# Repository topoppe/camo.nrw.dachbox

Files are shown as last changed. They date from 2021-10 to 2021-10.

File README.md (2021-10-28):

Im Rahmen des EFRE-geförderten Projektes CAMO.NRW forschen Mitarbeiter der Hochschule Ruhr West zusammen mit Kollegen der Bergischen Universität Wuppertal und der Bergischen Struktur- & Wirtschaftsförderungsgesellschaft an der Zukunft der automatisierten Mobilität. An der Hochschule bestand schon eine Experimentalplattform bestehend aus verschiedenen Kameras, Radarsensoren, LiDAR und mehreren GNSS.
Jene Plattform war im Kofferraum eines PKWs verbaut, jedoch ohne die Beachtung gängiger Sicherheitsvorschriften und Normen. 
Durch die komplexe Einbauweise war die gesamte Plattform an einen einzelnen PKW gebunden. 
Im Rahmen dieser Arbeit wurde die vorhandene Sensortechnik auf einem austauschbaren Geräteträger montiert. Hierbei wurde sowohl auf Sicherheitsvorschriften als auch auf die einfache Montagemöglichkeit auf verschiedenen PKW geachtet. 
Der entstandene Geräteträger kann nun sowohl mobil als auch stationär, auf einem beliebigen PKW montiert oder in einer Laborumgebung ohne PKW genutzt werden.

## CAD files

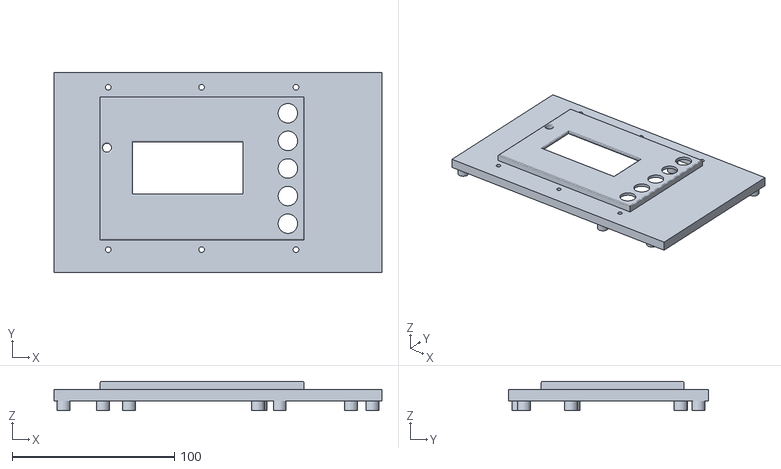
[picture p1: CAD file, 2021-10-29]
Mechanik/Gehäuse Steuergerät/aussenteil.stl
202.0 x 123.0 x 18.0

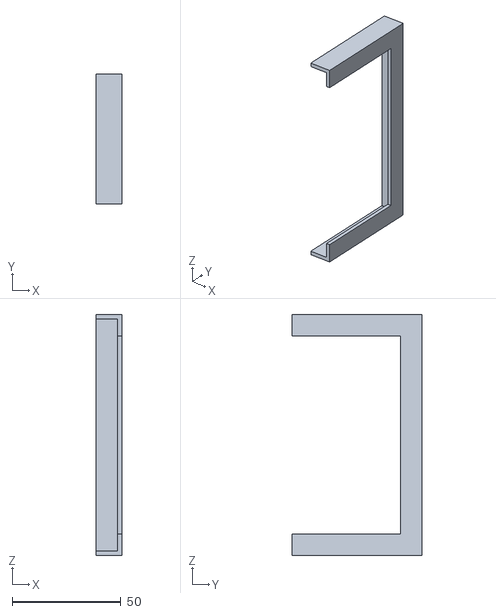
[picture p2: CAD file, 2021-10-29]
Mechanik/Halterung Cam-Sync-Box/Halterung Sync-Box v2.stl
12.0 x 60.0 x 111.0

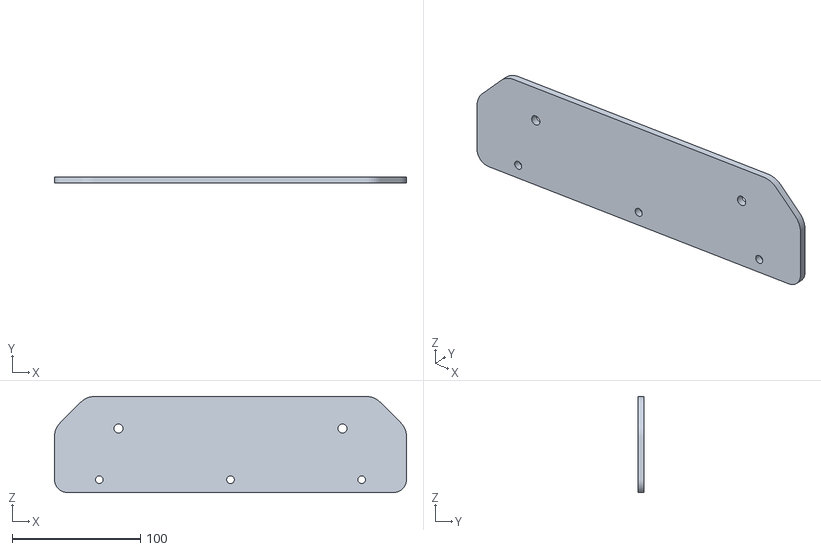
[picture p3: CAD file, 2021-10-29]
Mechanik/Halterung GPS/halterung gps v2.stl
275.0 x 5.00 x 75.0

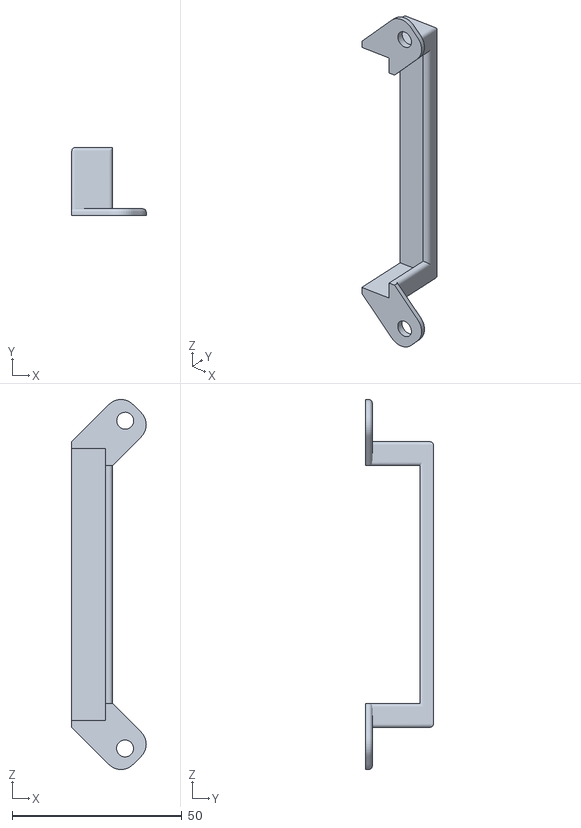
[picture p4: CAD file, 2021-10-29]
Mechanik/Halterung HDBaseT Sender/halterung_hdbaset_sender v1.stl
21.9 x 20.0 x 108.8

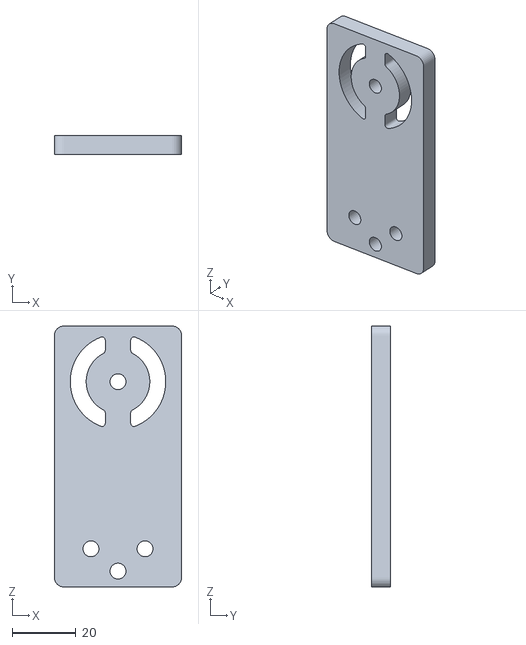
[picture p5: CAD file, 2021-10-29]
Mechanik/Halterung Kamera BlueFox/Halterung Kamera BlueFOX v2.stl
40.0 x 6.00 x 82.0

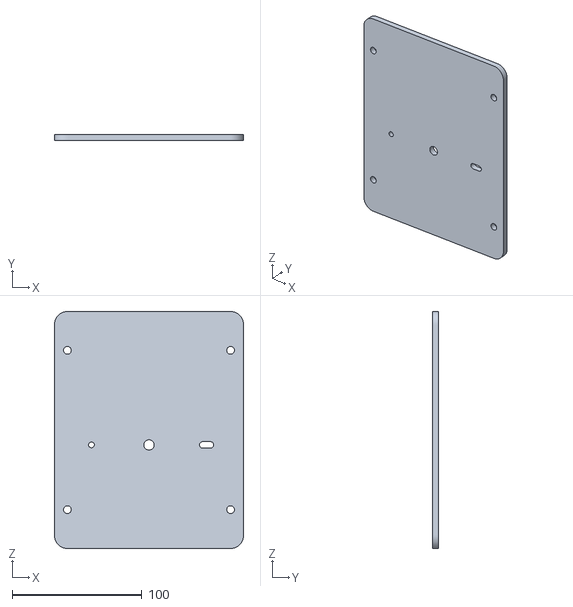
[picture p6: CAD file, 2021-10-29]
Mechanik/Halterung Lidar/halteplatte_lidart v2.stl
146.0 x 5.00 x 183.0

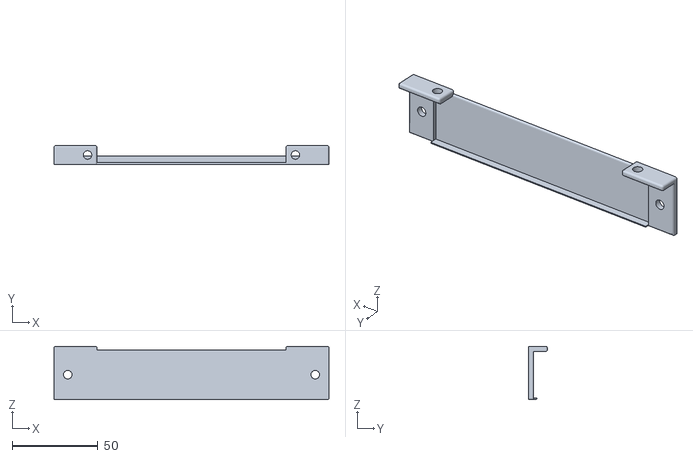
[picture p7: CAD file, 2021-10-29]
Mechanik/Halterung Netzteil 5V/halterung netzteil 5v v1.stl
160.0 x 11.0 x 31.0

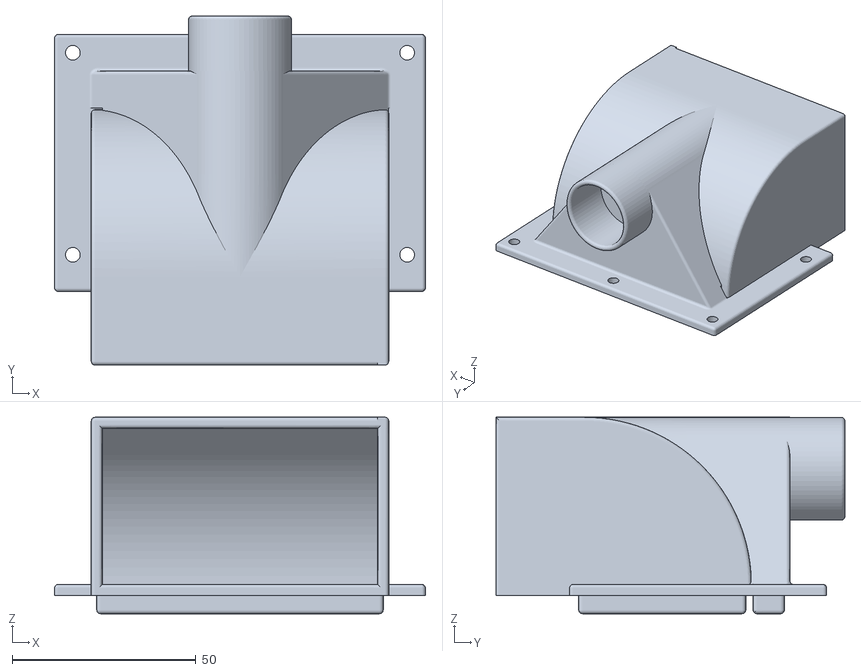
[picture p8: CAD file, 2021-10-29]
Mechanik/Kabelauslass/kabelauslass_innen v6.stl
101.0 x 95.0 x 53.5

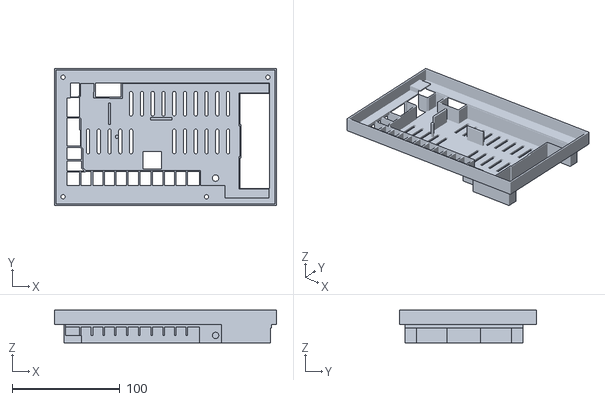
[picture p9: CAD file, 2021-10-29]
Mechanik/Gehäuse Steuergerät/deckel.stl
206.0 x 127.0 x 30.6

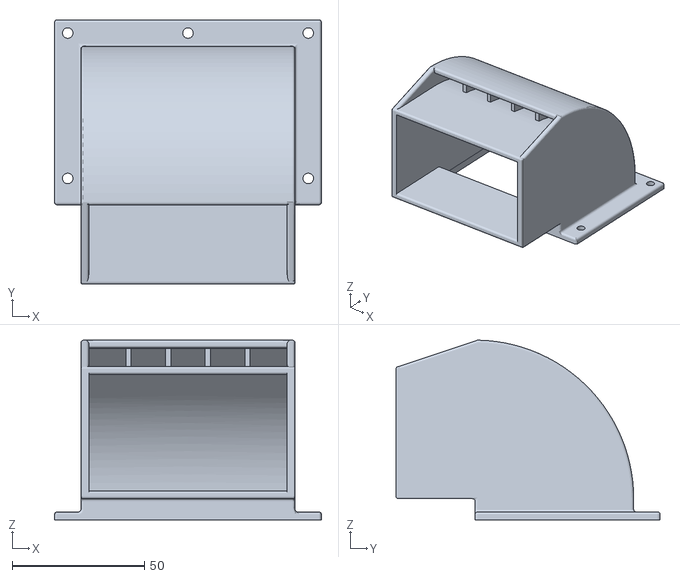
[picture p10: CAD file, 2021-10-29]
Mechanik/Kabelauslass/kabelauslass_aussen v8.stl
101.0 x 100.0 x 68.0

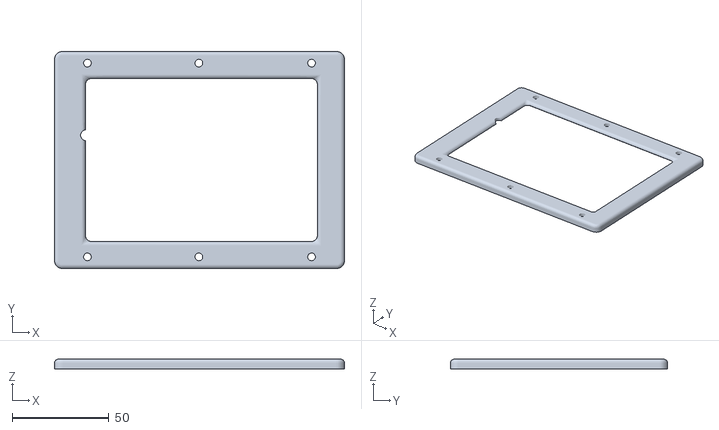
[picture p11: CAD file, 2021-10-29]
Mechanik/Gehäuse Steuergerät/rahmenabdeckung.stl
149.6 x 112.0 x 5.00

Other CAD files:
Mechanik/Halterung Cam-Sync-Box/Halterung Sync-Box v2.f3d
Mechanik/Halterung GPS/halterung gps v2.f3d
Mechanik/Halterung HDBaseT Sender/halterung_hdbaset_sender v1.f3d
Mechanik/Halterung Kamera BlueFox/Halterung Kamera BlueFOX v2.f3d
Mechanik/Halterung Lidar/halteplatte_lidart v2.f3d
Mechanik/Halterung Netzteil 5V/halterung netzteil 5v v1.f3d
Mechanik/Kabelauslass/kabelauslass_aussen v8.f3d
Mechanik/Kabelauslass/kabelauslass_innen v6.f3d

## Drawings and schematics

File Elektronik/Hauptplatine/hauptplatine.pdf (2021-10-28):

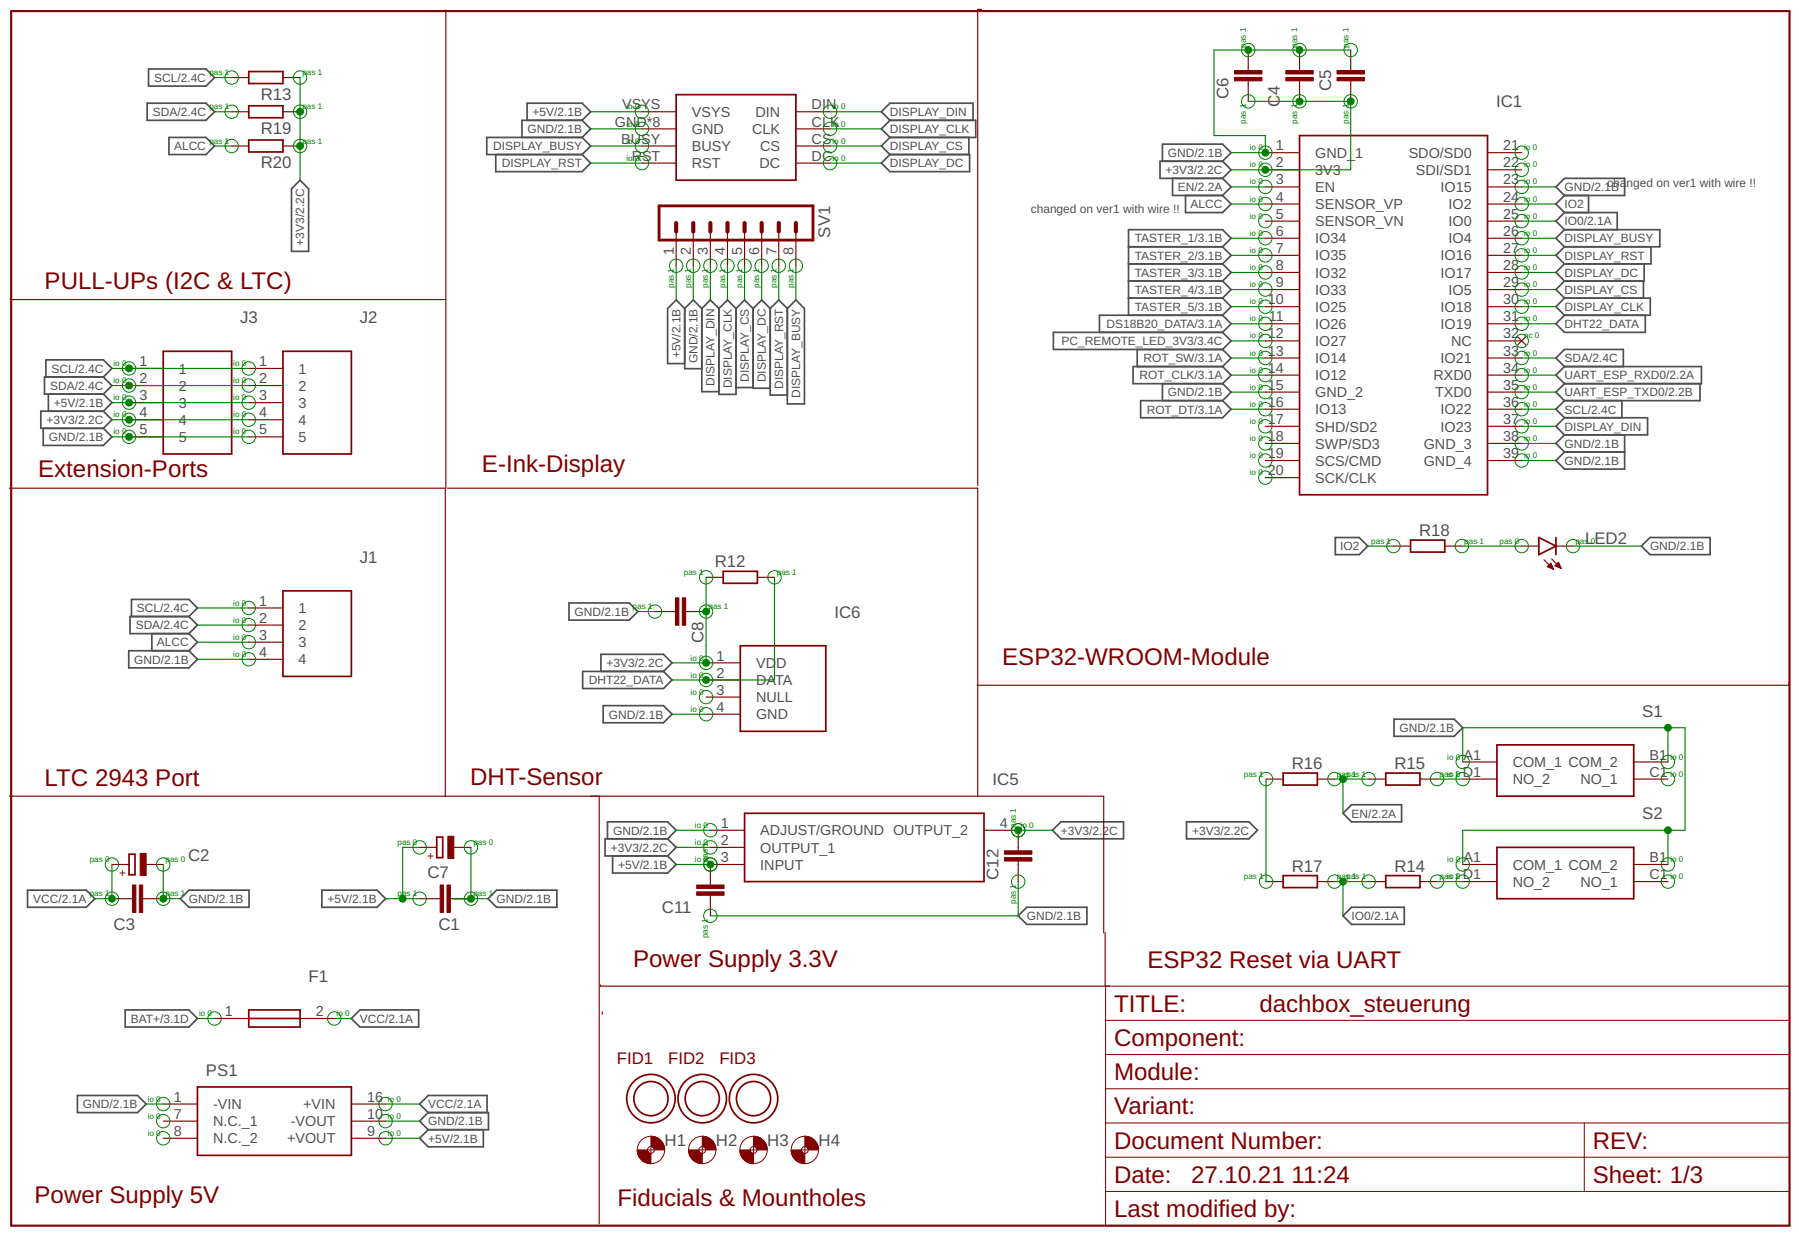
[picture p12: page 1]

2 | 2 io 0
3 | io 0 3
4 | 4 io 0

LTC 2943 Port | | J1 | DHT-Sensor

FID1 FID2 FID3 H1 H2 H3 H4 Fiducials & Mountholes | TITLE: dachbox_steuerung

Document Number: | REV:
Date: 27.10.21 11:24 | Sheet: 1/3

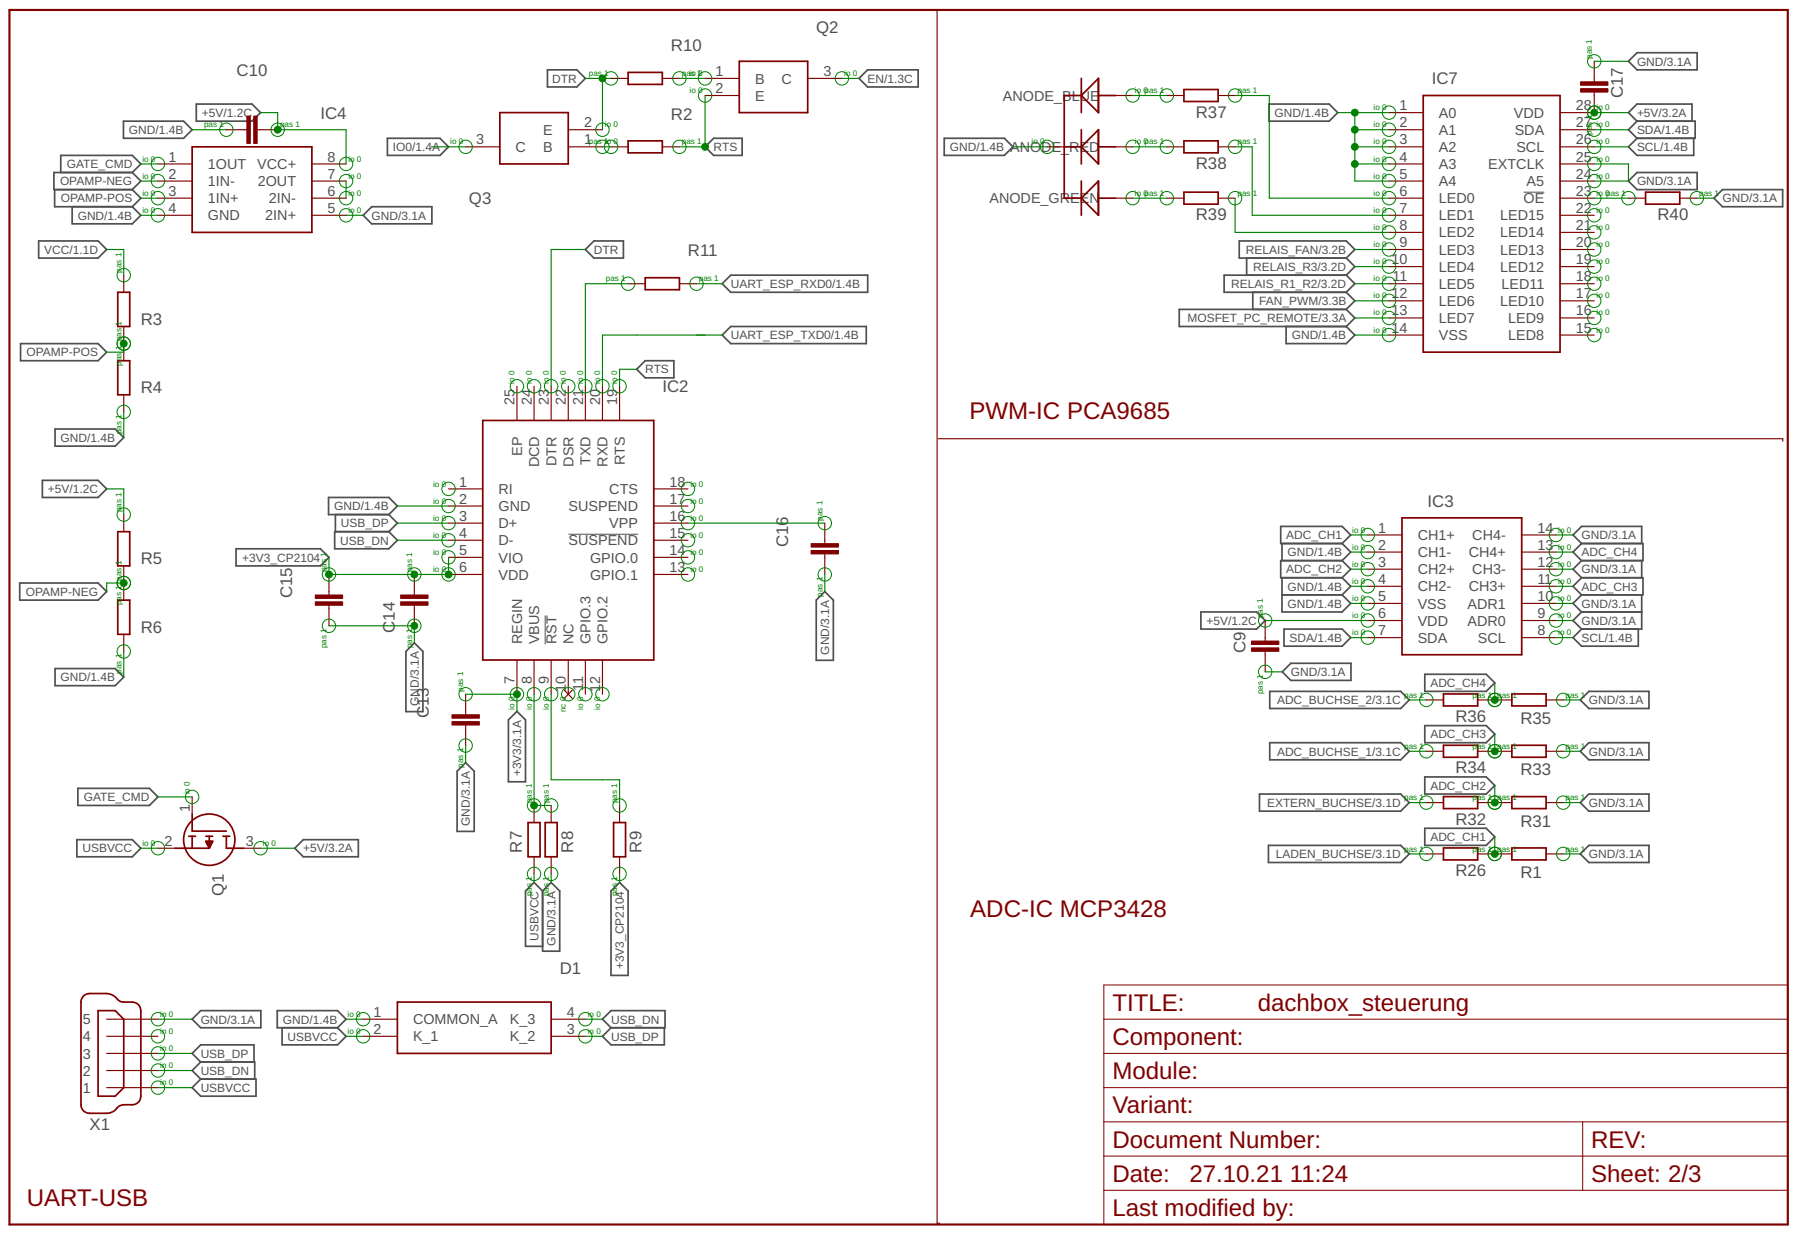
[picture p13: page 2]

pas 1 pas 1 pas 1 pas 1

Document Number: | REV:
Date: 27.10.21 11:24 | Sheet: 2/3

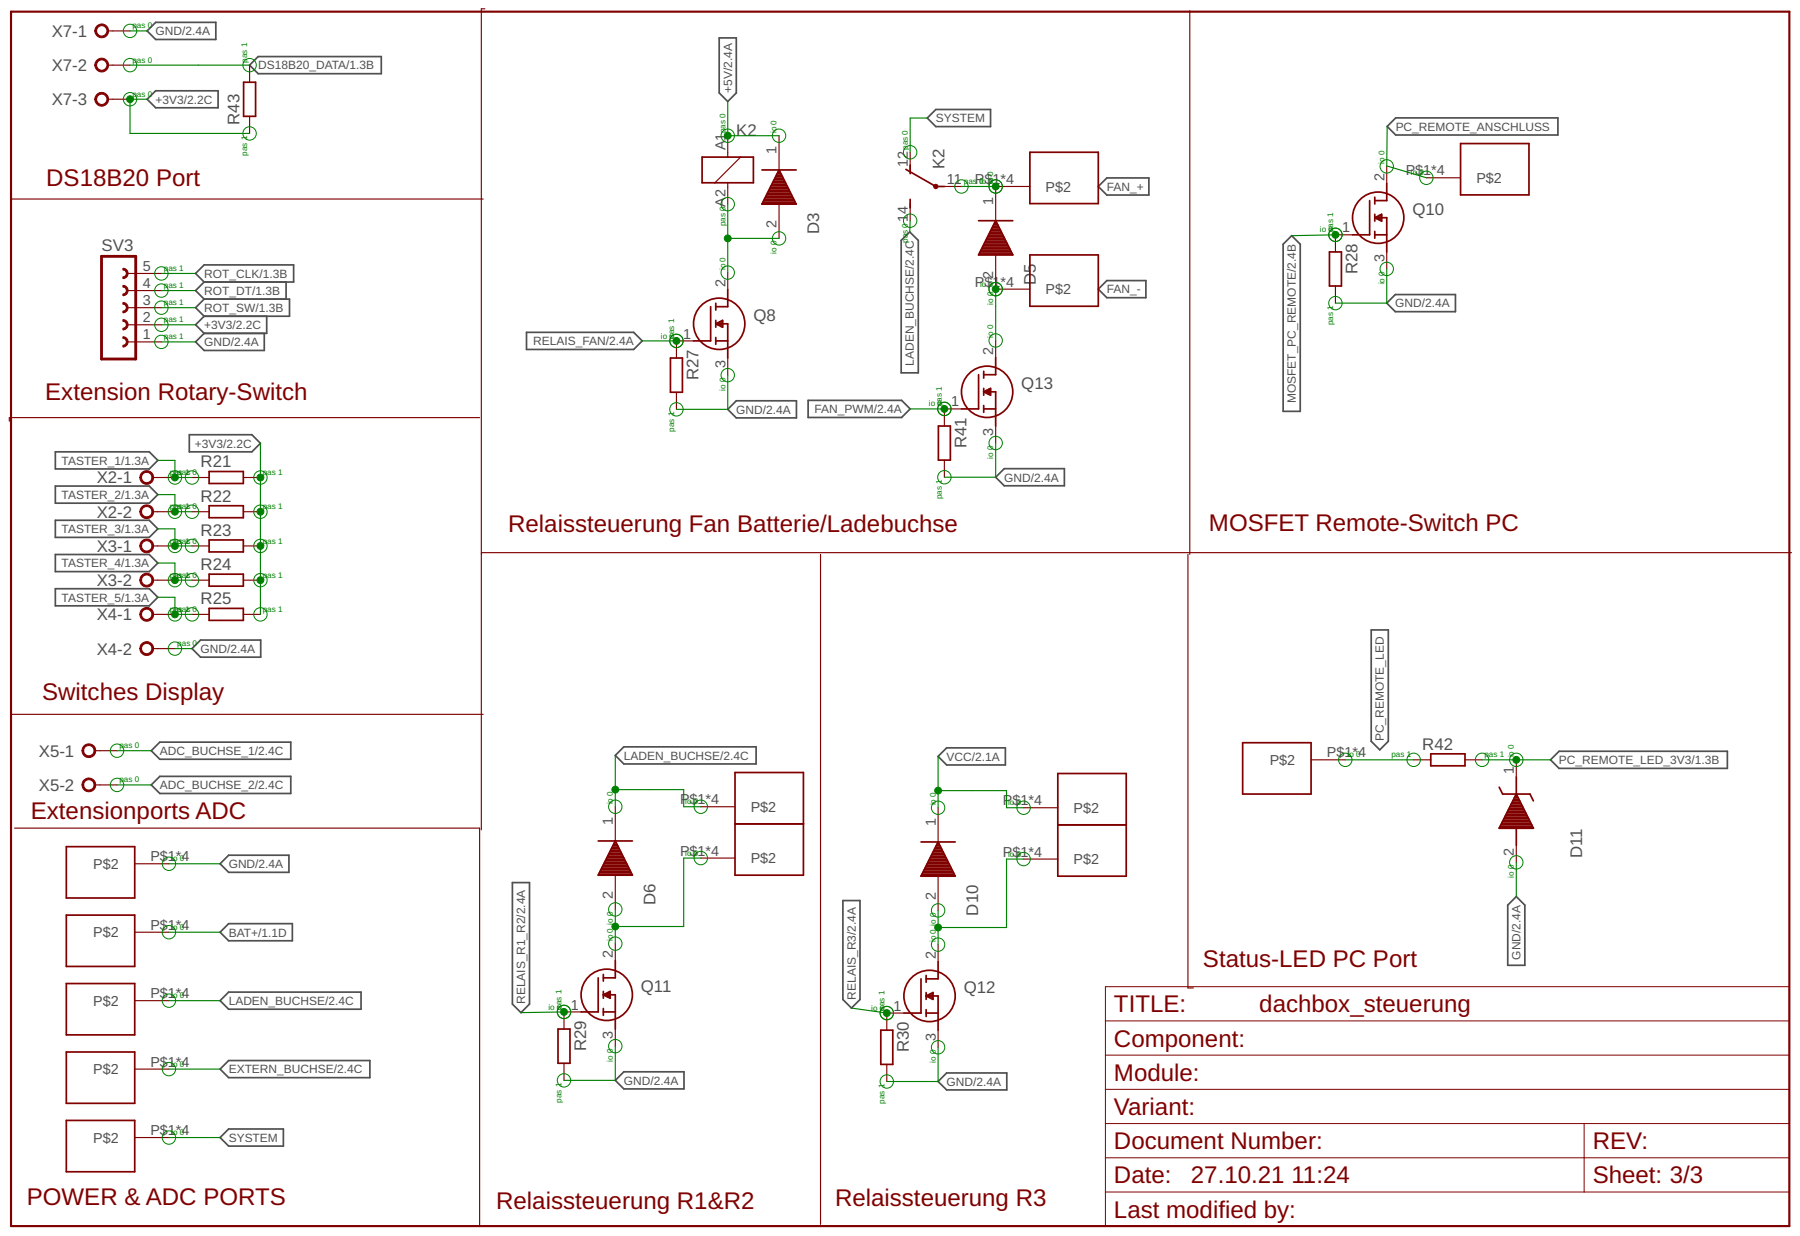
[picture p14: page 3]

io 0 io 0 pas 0 pas 0

Status-LED PC Port
dachbox_steuerung

Document Number: | REV:
Date: 27.10.21 11:24 | Sheet: 3/3

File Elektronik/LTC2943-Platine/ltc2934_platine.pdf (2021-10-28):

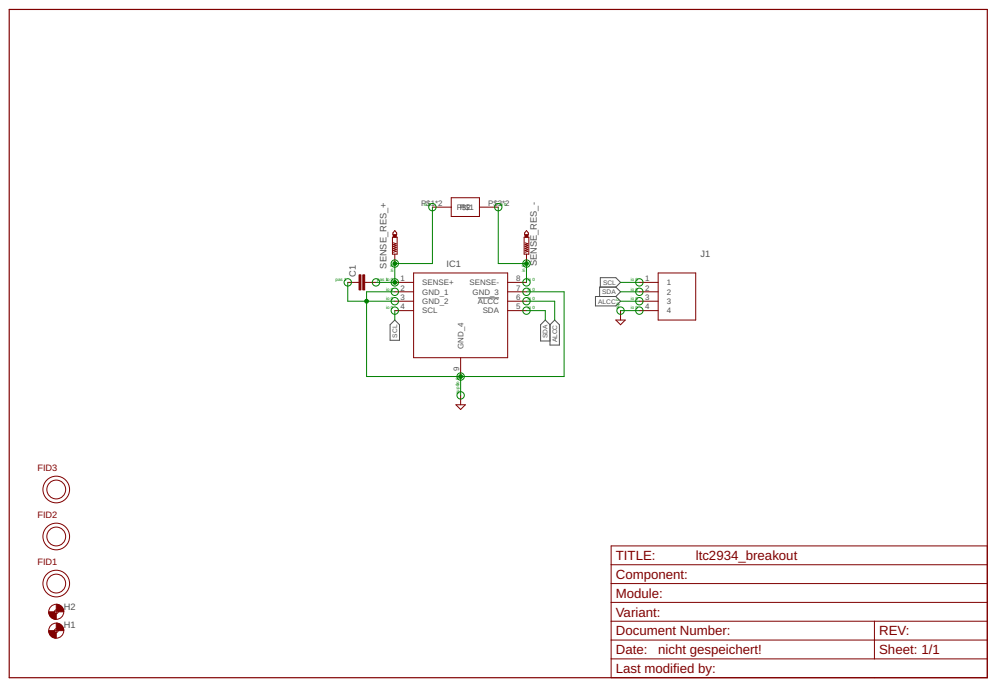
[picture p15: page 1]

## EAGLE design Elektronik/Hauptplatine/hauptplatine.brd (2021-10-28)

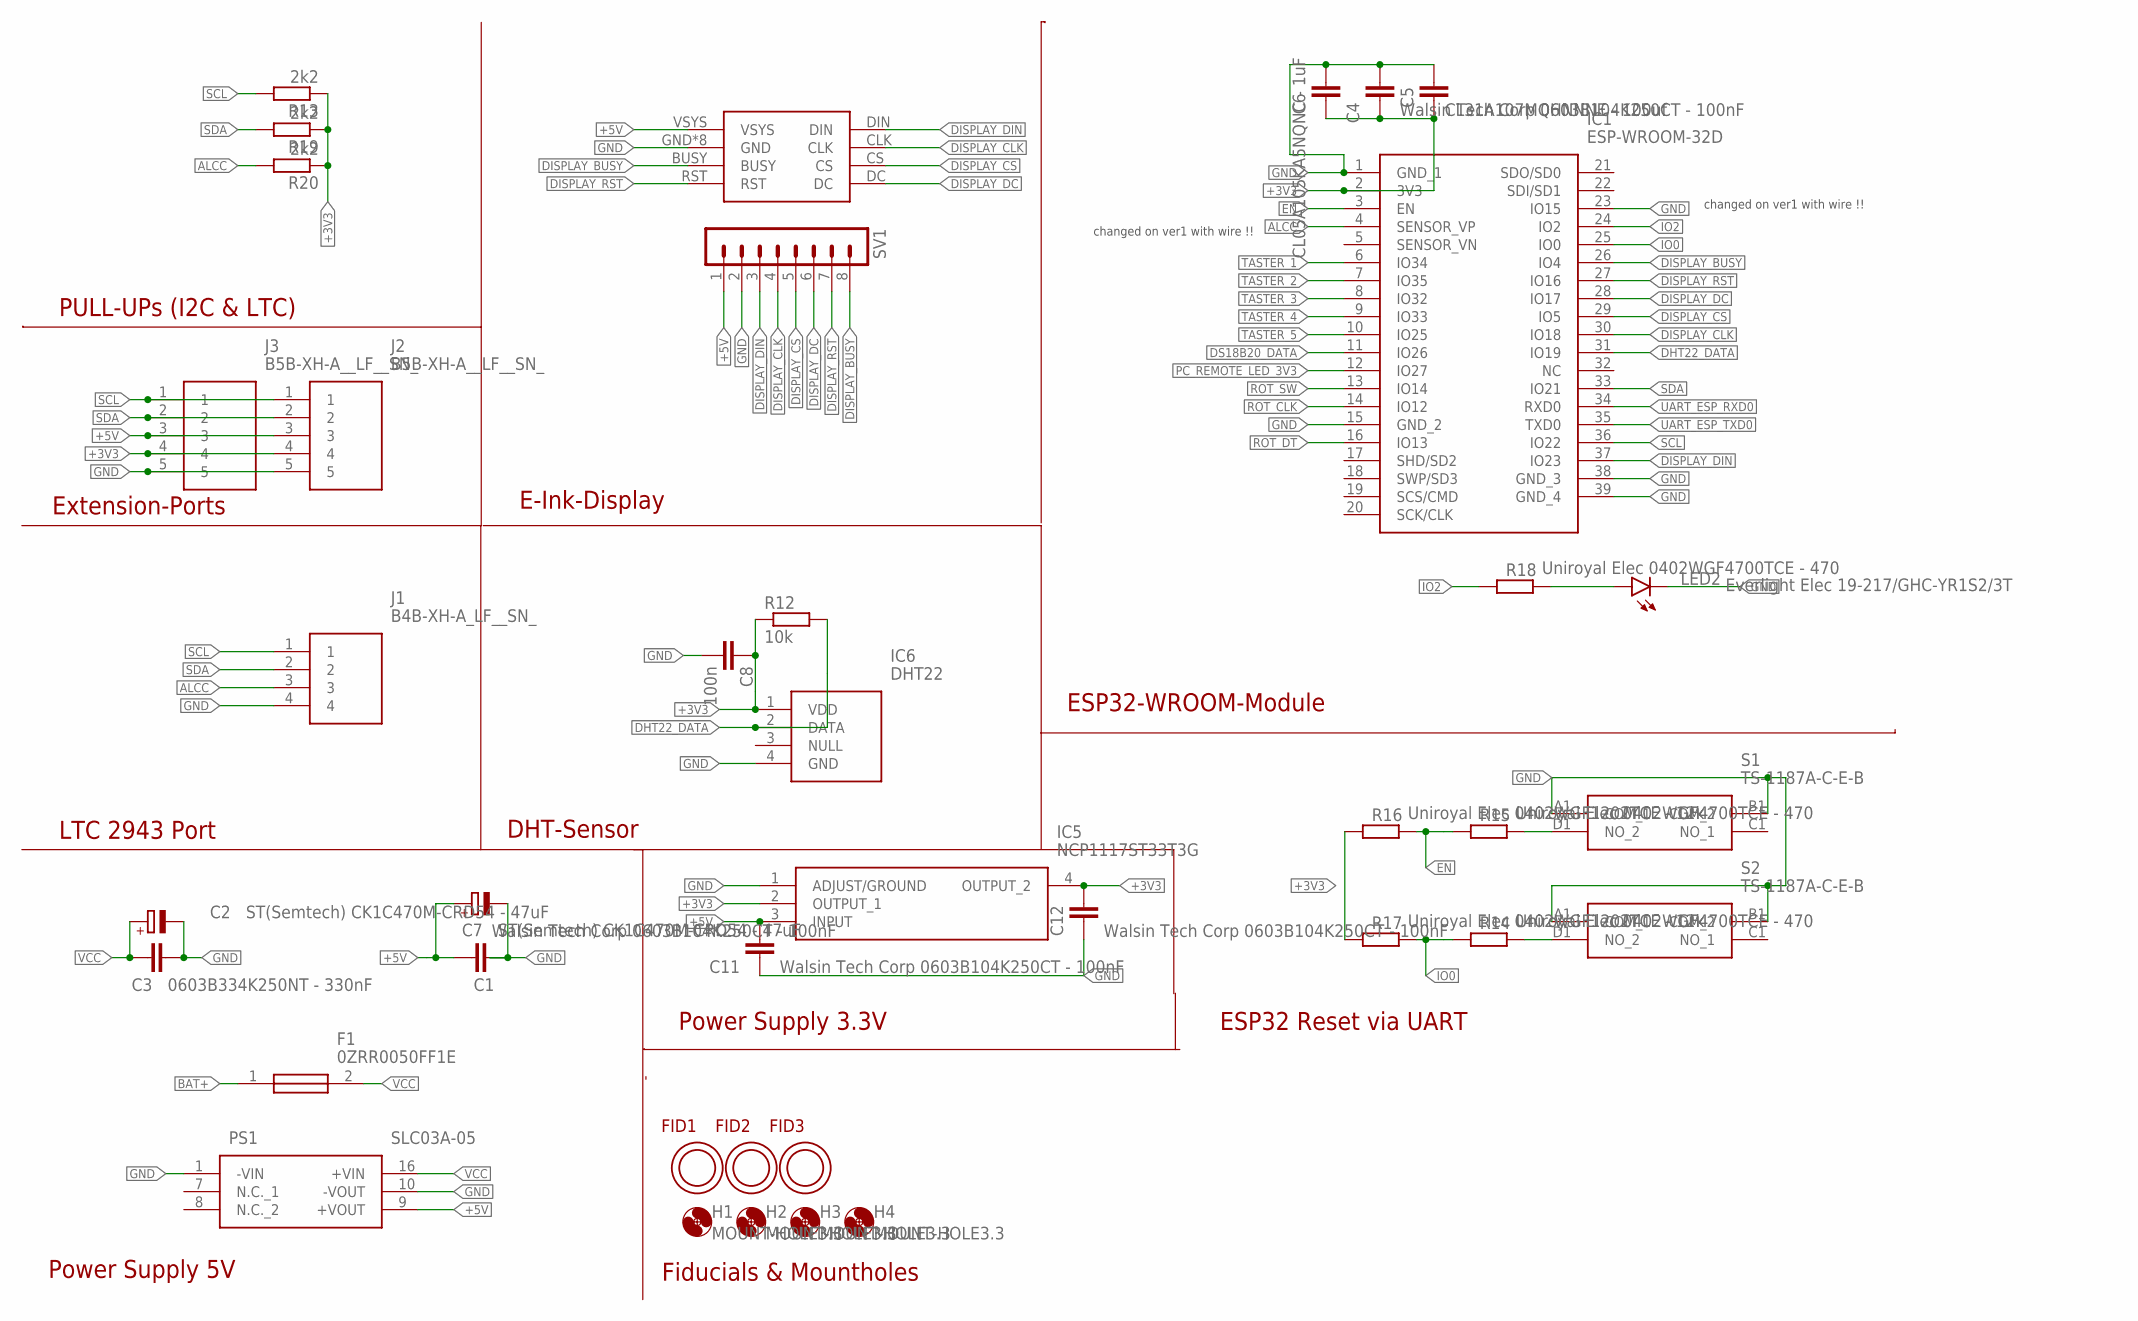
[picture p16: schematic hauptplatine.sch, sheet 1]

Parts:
C1, C4, C11, C12: Walsin Tech Corp 0603B104K250CT - 100nF; C0603
C2, C7: ST(Semtech) CK1C470M-CRD54 - 47uF; PANASONIC_C
C3: 0603B334K250NT - 330nF; C0603
C5: CL31A107MQHNNNE - 100uf; C1206
C6: CL05A105KA5NQNC - 1uF; C0402
C8: 100n; C1206
F1: 0ZRR0050FF1E
FID1, FID2, FID3: OPEN-PNP-FIDUCIAL
H1, H2, H3, H4: MOUNT-HOLE3.3; 3,3
IC1: ESP-WROOM-32D; ESPWROOM32D
IC5: NCP1117ST33T3G; SOT230P700X180-4N
IC6: DHT22
J1: B4B-XH-A_LF__SN_; B4BXHALFSN
J2, J3: B5B-XH-A__LF__SN_; SHDR5W64P0X250_1X5_1490X575X70
LED2: Everlight Elec 19-217/GHC-YR1S2/3T; CHIPLED_0603
PS1: SLC03A-05; SLC03A05
R12: 10k; R1206
R13, R19, R20: 2k2; R1206
R14, R15, R18: Uniroyal Elec 0402WGF4700TCE - 470; R0402
R16, R17: Uniroyal Elec 0402WGF1202TCE - 12k; R0402
S1, S2: TS-1187A-C-E-B; TS1187ACEB
SV1: MA08-1
U$1: PICO-EPAPER-2.9-V3

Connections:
+3V3: C4.1, C5.2, C6.1, C8.1, C12.2, IC1.2 (3V3), IC5.2 (OUTPUT_1), IC5.4 (OUTPUT_2), IC6.1 (VDD), J2.4, J3.4, R12.1, R13.1, R16.1, R17.1, R19.1, R20.1; also elsewhere on the board
+5V: C1.1, C7.+, C11.2, IC5.3 (INPUT), J2.3, J3.3, PS1.9 (+VOUT), SV1.1, U$1.VSYS; also elsewhere on the board
ALCC: IC1.4 (SENSOR_VP), J1.3, R20.2
BAT+: F1.1; also elsewhere on the board
DHT22_DATA: IC1.31 (IO19), IC6.2 (DATA), R12.2
DISPLAY_BUSY: IC1.26 (IO4), SV1.8, U$1.BUSY
DISPLAY_CLK: IC1.30 (IO18), SV1.4, U$1.CLK
DISPLAY_CS: IC1.29 (IO5), SV1.5, U$1.CS
DISPLAY_DC: IC1.28 (IO17), SV1.6, U$1.DC
DISPLAY_DIN: IC1.37 (IO23), SV1.3, U$1.DIN
DISPLAY_RST: IC1.27 (IO16), SV1.7, U$1.RST
DS18B20_DATA: IC1.11 (IO26); also elsewhere on the board
EN: IC1.3 (EN), R15.1, R16.2; also elsewhere on the board
GND: C1.2, C2.-, C3.1, C4.2, C5.1, C6.2, C7.-, C8.2, C11.1, C12.1, IC1.1 (GND_1), IC1.15 (GND_2), IC1.23 (IO15), IC1.38 (GND_3), IC1.39 (GND_4), IC5.1 (ADJUST/GROUND), IC6.4 (GND), J1.4, J2.5, J3.5, LED2.C, PS1.1 (-VIN), PS1.10 (-VOUT), S1.A1 (COM_1), S1.B1 (COM_2), S2.A1 (COM_1), S2.B1 (COM_2), SV1.2, U$1.GND, U$1.GND1 (GND), U$1.GND2 (GND), U$1.GND3 (GND), U$1.GND4 (GND), U$1.GND5 (GND), U$1.GND6 (GND), U$1.GND7 (GND); also elsewhere on the board
IO0: IC1.25 (IO0), R14.1, R17.2; also elsewhere on the board
IO2: IC1.24 (IO2), R18.1
unnamed: R15.2, S1.D1 (NO_2)
unnamed: R14.2, S2.D1 (NO_2)
unnamed: LED2.A, R18.2
PC_REMOTE_LED_3V3: IC1.12 (IO27); also elsewhere on the board
ROT_CLK: IC1.14 (IO12); also elsewhere on the board
ROT_DT: IC1.16 (IO13); also elsewhere on the board
ROT_SW: IC1.13 (IO14); also elsewhere on the board
SCL: IC1.36 (IO22), J1.1, J2.1, J3.1, R13.2; also elsewhere on the board
SDA: IC1.33 (IO21), J1.2, J2.2, J3.2, R19.2; also elsewhere on the board
TASTER_1: IC1.6 (IO34); also elsewhere on the board
TASTER_2: IC1.7 (IO35); also elsewhere on the board
TASTER_3: IC1.8 (IO32); also elsewhere on the board
TASTER_4: IC1.9 (IO33); also elsewhere on the board
TASTER_5: IC1.10 (IO25); also elsewhere on the board
UART_ESP_RXD0: IC1.34 (RXD0); also elsewhere on the board
UART_ESP_TXD0: IC1.35 (TXD0); also elsewhere on the board
VCC: C2.+, C3.2, F1.2, PS1.16 (+VIN); also elsewhere on the board

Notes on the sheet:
Power Supply 5V
changed on ver1 with wire !!
DHT-Sensor
Extension-Ports
PULL-UPs (I2C & LTC)
E-Ink-Display
LTC 2943 Port
ESP32-WROOM-Module
ESP32 Reset via UART
Power Supply 3.3V
Fiducials & Mountholes

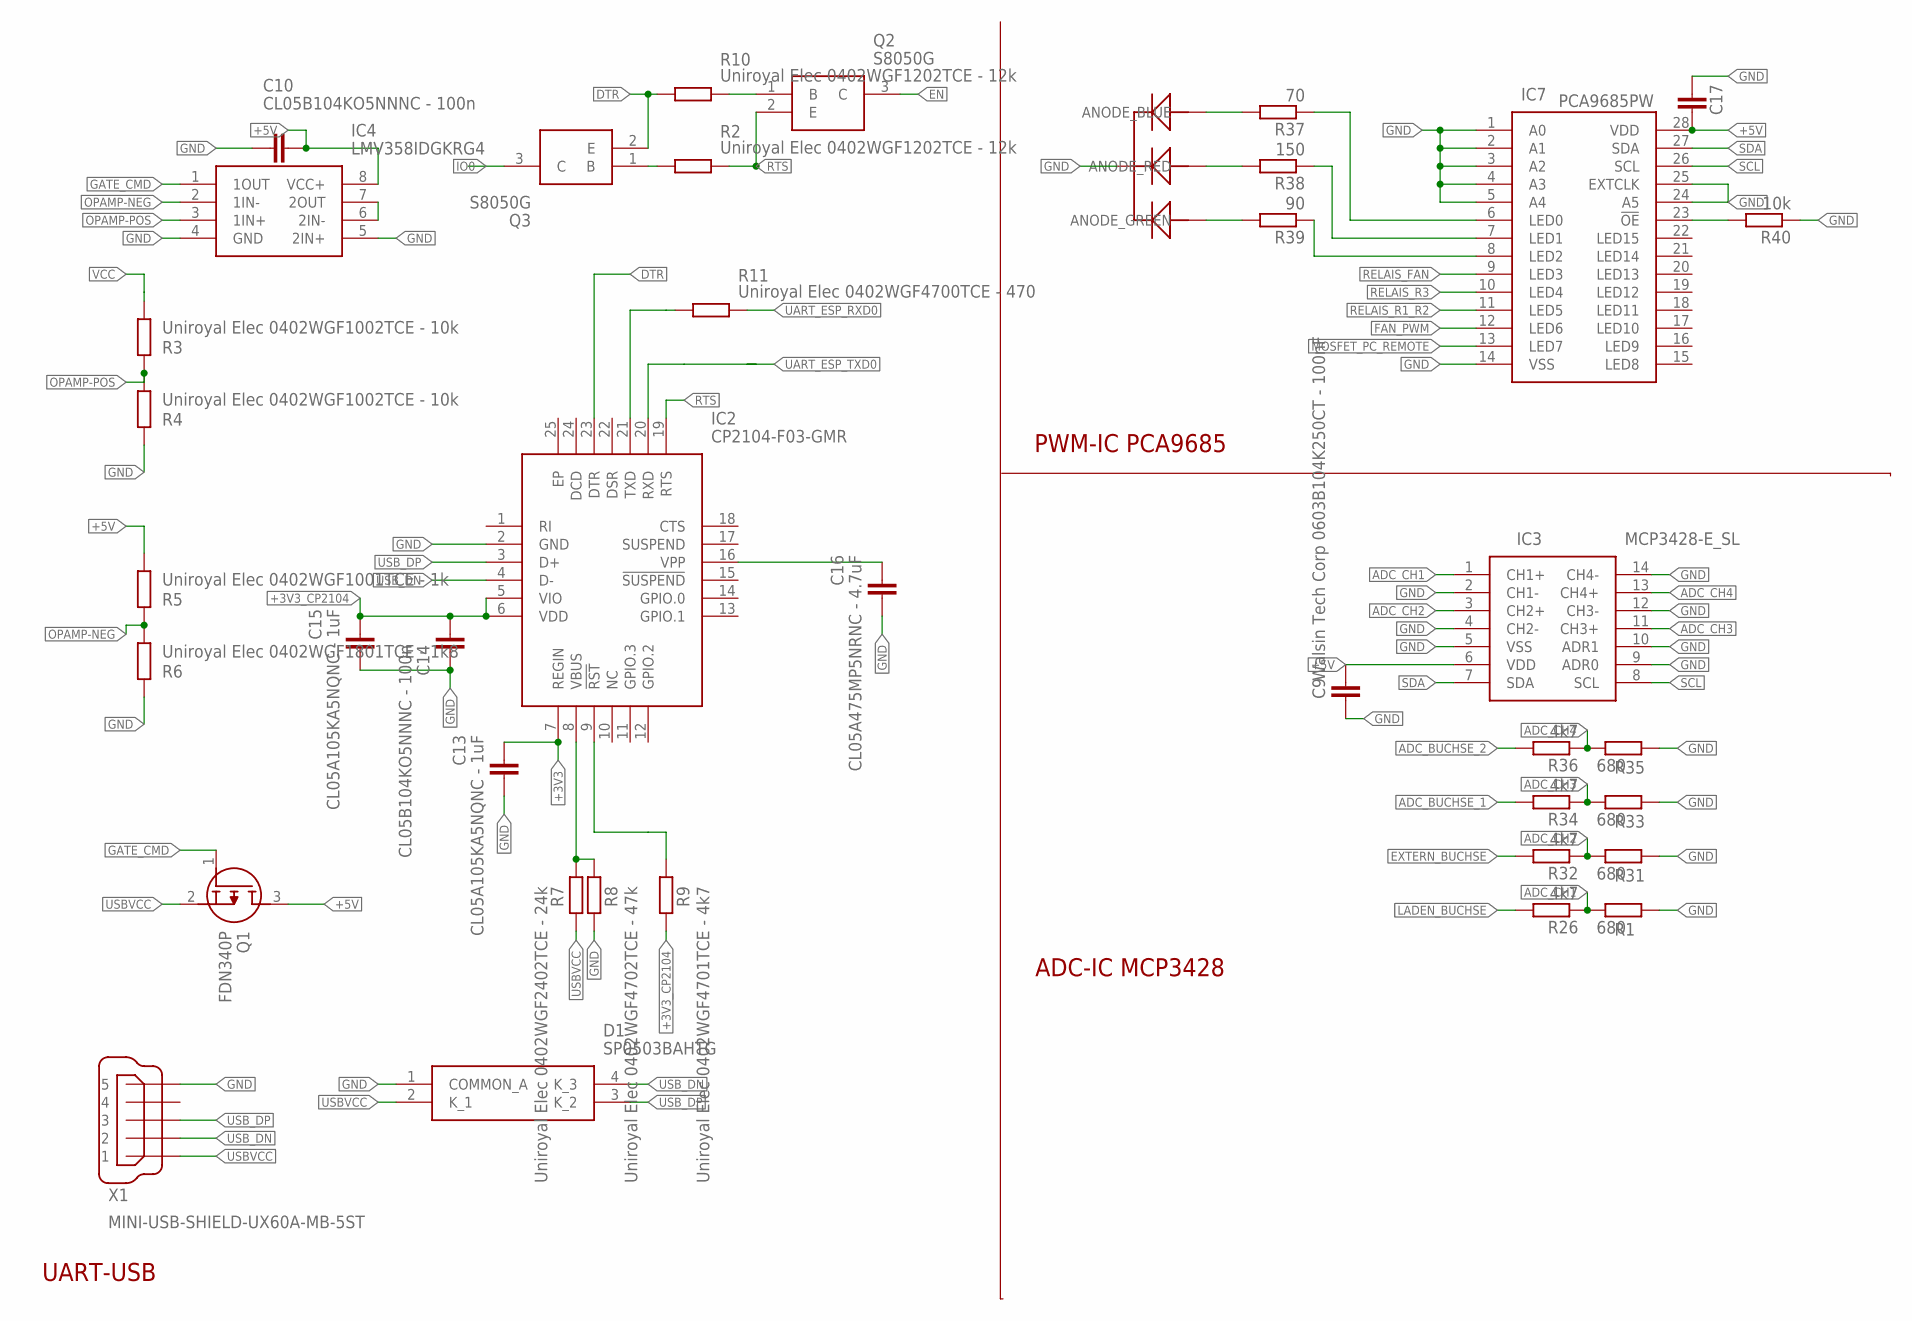
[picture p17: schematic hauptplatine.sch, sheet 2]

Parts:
C9, C17: Walsin Tech Corp 0603B104K250CT - 100nF; C0603
C10, C14: CL05B104KO5NNNC - 100n; C0402
C13, C15: CL05A105KA5NQNC - 1uF; C0402
C16: CL05A475MP5NRNC - 4.7uF; C0402
D1: SP0503BAHTG
IC2: CP2104-F03-GMR; QFN50P400X400X80-25N
IC3: MCP3428-E_SL; SOIC127P600X175-14N
IC4: LMV358IDGKRG4; SOP65P490X110-8N
IC7: PCA9685PW; SOP65P640X110-28N
Q1: FDN340P; SOT95P237X112-3N
Q2, Q3: S8050G; SOT95P240X110-3N
R1, R31, R33, R35: 680; R1206
R2, R10: Uniroyal Elec 0402WGF1202TCE - 12k; R0402
R3, R4: Uniroyal Elec 0402WGF1002TCE - 10k; R0402
R5: Uniroyal Elec 0402WGF1001TCE - 1k; R0402
R6: Uniroyal Elec 0402WGF1801TCE - 1k8; R0402
R7: Uniroyal Elec 0402WGF2402TCE - 24k; R0402
R8: Uniroyal Elec 0402WGF4702TCE - 47k; R0402
R9: Uniroyal Elec 0402WGF4701TCE - 4k7; R0402
R11: Uniroyal Elec 0402WGF4700TCE - 470; R0402
R26, R32, R34, R36: 4k7; R1206
R37: 70; R1206
R38: 150; R1206
R39: 90; R1206
R40: 10k; R1206
U$12: RG_LED_5MM; RGB_LED_5MM
X1: MINI-USB-SHIELD-UX60A-MB-5ST; UX60A-MB-5ST

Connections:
+3V3: C13.2, IC2.7 (REGIN); also elsewhere on the board
+3V3_CP2104: C14.2, C15.2, IC2.5 (VIO), IC2.6 (VDD), R9.2
+5V: C9.2, C10.2, C17.1, IC3.6 (VDD), IC4.8 (VCC+), IC7.28 (VDD), Q1.3 (D), R5.1; also elsewhere on the board
ADC_BUCHSE_1: R34.2; also elsewhere on the board
ADC_BUCHSE_2: R36.2; also elsewhere on the board
ADC_CH1: IC3.1 (CH1+), R1.1, R26.1
ADC_CH2: IC3.3 (CH2+), R31.1, R32.1
ADC_CH3: IC3.11 (CH3+), R33.1, R34.1
ADC_CH4: IC3.13 (CH4+), R35.1, R36.1
DTR: IC2.23 (DTR), Q3.2 (E), R10.1
EN: Q2.3 (C); also elsewhere on the board
EXTERN_BUCHSE: R32.2; also elsewhere on the board
FAN_PWM: IC7.12 (LED6); also elsewhere on the board
GATE_CMD: IC4.1 (1OUT), Q1.1 (G)
GND: C9.1, C10.1, C13.1, C14.1, C15.1, C16.1, C17.2, D1.1 (COMMON_A), IC2.2 (GND), IC3.2 (CH1-), IC3.4 (CH2-), IC3.5 (VSS), IC3.9 (ADR0), IC3.10 (ADR1), IC3.12 (CH3-), IC3.14 (CH4-), IC4.4 (GND), IC4.5 (2IN+), IC7.1 (A0), IC7.2 (A1), IC7.3 (A2), IC7.4 (A3), IC7.5 (A4), IC7.14 (VSS), IC7.24 (A5), IC7.25 (EXTCLK), R1.2, R4.2, R6.2, R8.2, R31.2, R33.2, R35.2, R40.1, U$12.CATHODE, X1.5; also elsewhere on the board
IO0: Q3.3 (C); also elsewhere on the board
LADEN_BUCHSE: R26.2; also elsewhere on the board
MOSFET_PC_REMOTE: IC7.13 (LED7); also elsewhere on the board
unnamed: Q3.1 (B), R2.1
unnamed: IC4.6 (2IN-), IC4.7 (2OUT)
unnamed: IC2.8 (VBUS), R7.1, R8.1
unnamed: IC2.9 (!RST), R9.1
unnamed: C16.2, IC2.16 (VPP)
unnamed: IC2.21 (TXD), R11.1
unnamed: Q2.1 (B), R10.2
unnamed: R39.2, U$12.ANODE_GREEN
unnamed: R37.2, U$12.ANODE_BLUE
unnamed: R38.2, U$12.ANODE_RED
unnamed: IC7.23 (!OE), R40.2
OPAMP-NEG: IC4.2 (1IN-), R5.2, R6.1
OPAMP-POS: IC4.3 (1IN+), R3.2, R4.1
RELAIS_FAN: IC7.9 (LED3); also elsewhere on the board
RELAIS_R1_R2: IC7.11 (LED5); also elsewhere on the board
RELAIS_R3: IC7.10 (LED4); also elsewhere on the board
RGB_BLAU1: IC7.6 (LED0), R37.1
RGB_GREEN1: IC7.8 (LED2), R39.1
RGB_ROT1: IC7.7 (LED1), R38.1
RTS: IC2.19 (RTS), Q2.2 (E), R2.2
SCL: IC3.8 (SCL), IC7.26 (SCL); also elsewhere on the board
SDA: IC3.7 (SDA), IC7.27 (SDA); also elsewhere on the board
UART_ESP_RXD0: R11.2; also elsewhere on the board
UART_ESP_TXD0: IC2.20 (RXD); also elsewhere on the board
USBVCC: D1.2 (K_1), Q1.2 (S), R7.2, X1.1
USB_DN: D1.4 (K_3), IC2.4 (D-), X1.2
USB_DP: D1.3 (K_2), IC2.3 (D+), X1.3
VCC: R3.1; also elsewhere on the board

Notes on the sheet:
UART-USB
PWM-IC PCA9685
ADC-IC MCP3428

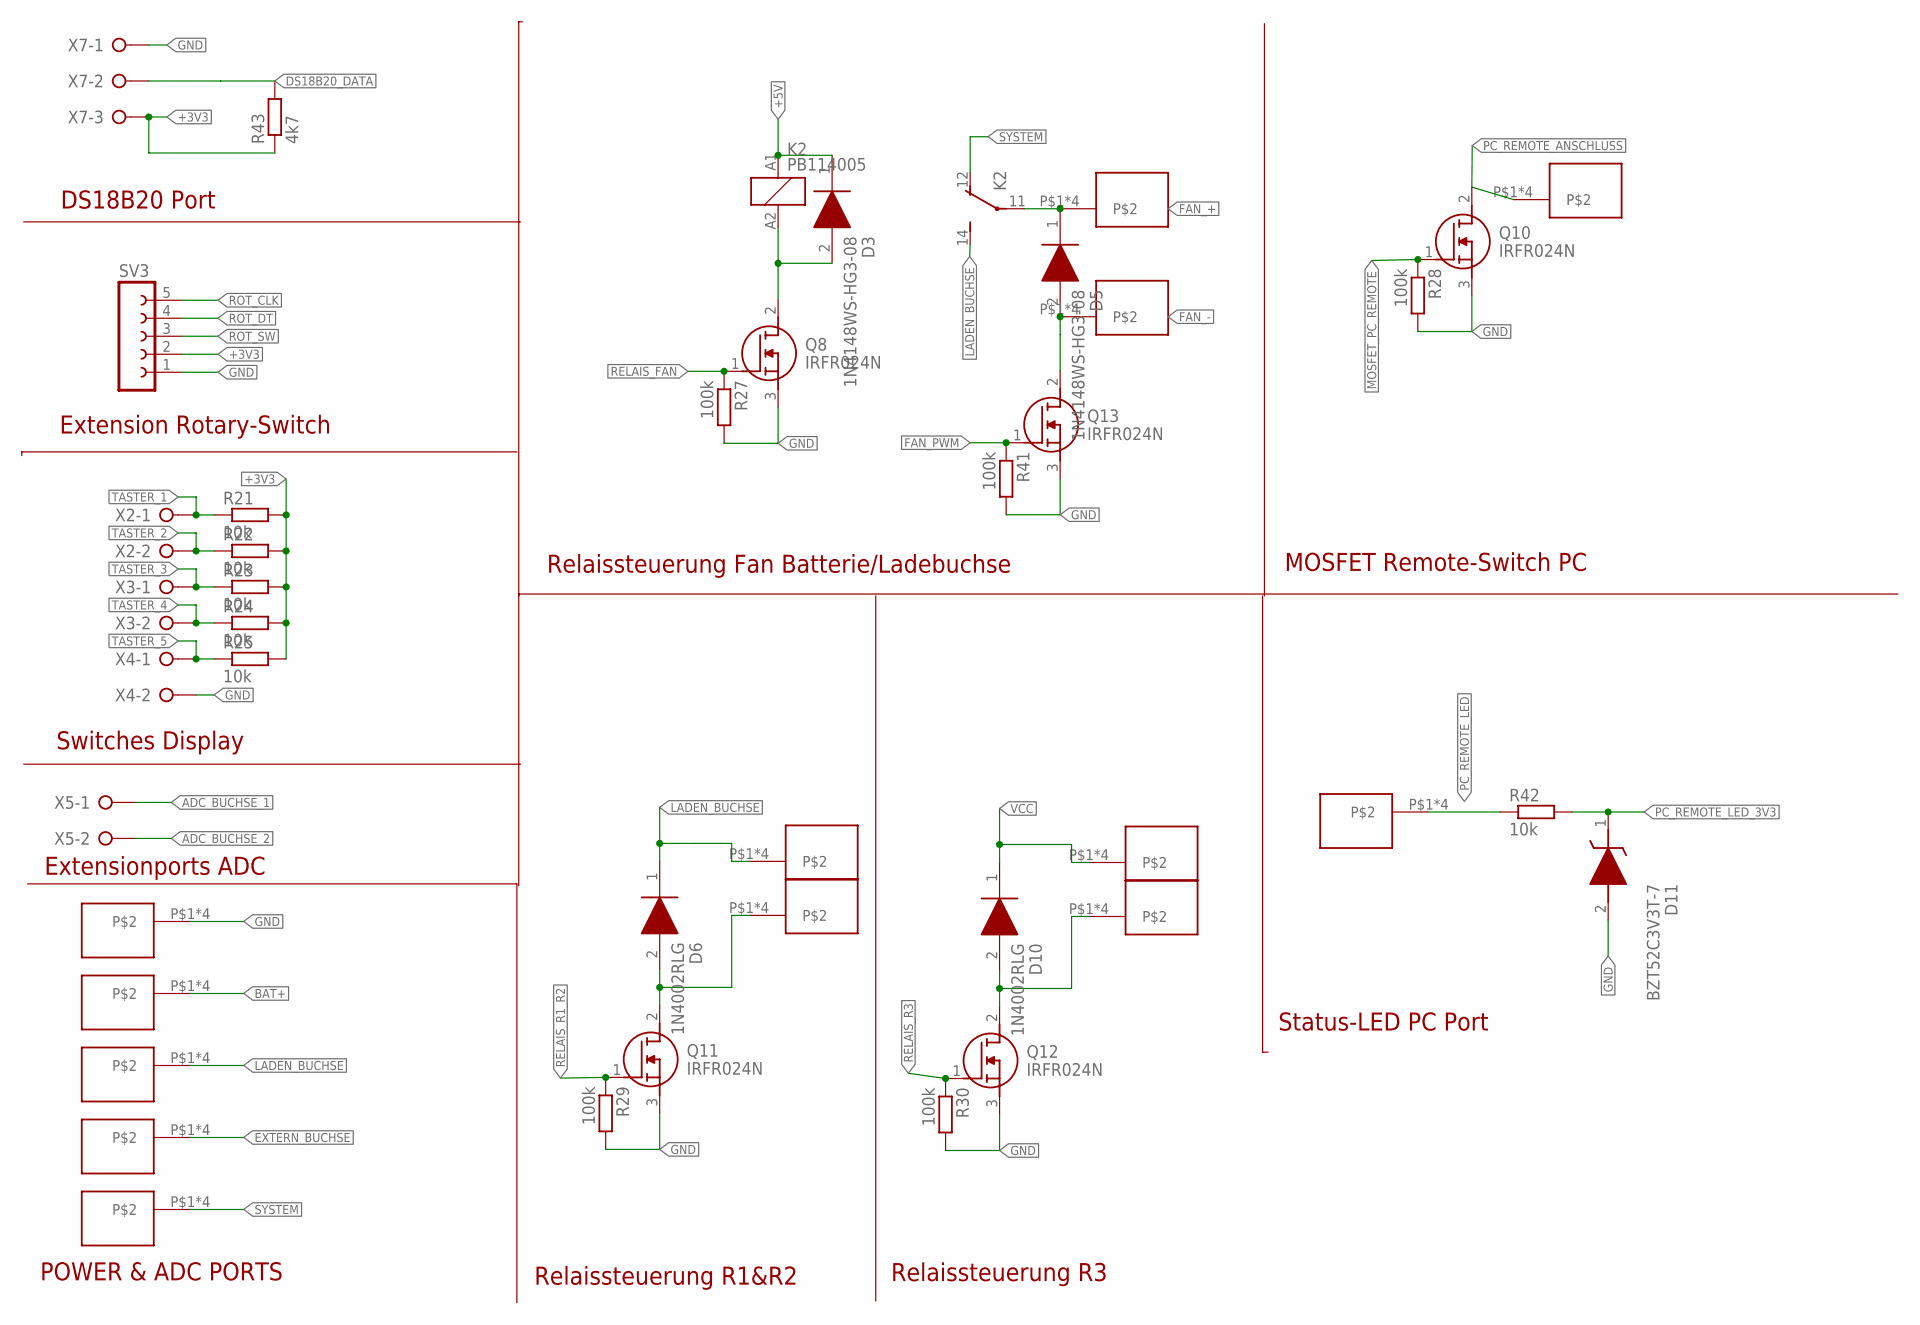
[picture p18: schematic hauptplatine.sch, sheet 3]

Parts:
D3, D5: 1N4148WS-HG3-08; SOD2713X115N
D6, D10: 1N4002RLG; DIOAD1405W86L465D235
D11: BZT52C3V3T-7; SODFL1608X65N
K2: PB114005; PB
Q8, Q10, Q11, Q12, Q13: IRFR024N; IRFR024TRPBFBE3
R21, R22, R23, R24, R25: 10k; R0805
R27, R28, R29, R30, R41: 100k; R1206
R42: 10k; R1206
R43: 4k7; R0805
SV3: FE05-1
U$2, U$17, U$18, U$19, U$20, U$21, U$22, U$23, U$24, U$25, U$26, U$27, U$28: WE-REDCUBE-74650173
X2, X3, X4, X5: W237-02P; W237-132
X7: W237-3E

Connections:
+3V3: R21.2, R22.2, R23.2, R24.2, R25.2, R43.1, SV3.2, X7.3; also elsewhere on the board
+5V: D3.1 (K), K2.A1 (1); also elsewhere on the board
ADC_BUCHSE_1: X5.1; also elsewhere on the board
ADC_BUCHSE_2: X5.2; also elsewhere on the board
BAT+: U$17.P$1, U$17.P$2, U$17.P$3, U$17.P$4; also elsewhere on the board
DS18B20_DATA: R43.2, X7.2; also elsewhere on the board
EXTERN_BUCHSE: U$19.P$1, U$19.P$2, U$19.P$3, U$19.P$4; also elsewhere on the board
FAN_+: D5.1 (K), K2.11, U$24.P$1, U$24.P$2, U$24.P$3, U$24.P$4
FAN_-: D5.2 (A), Q13.2 (D), U$27.P$1, U$27.P$2, U$27.P$3, U$27.P$4
FAN_PWM: Q13.1 (G), R41.1; also elsewhere on the board
GND: D11.2 (A), Q8.3 (S), Q10.3 (S), Q11.3 (S), Q12.3 (S), Q13.3 (S), R27.2, R28.2, R29.2, R30.2, R41.2, SV3.1, U$2.P$1, U$2.P$2, U$2.P$3, U$2.P$4, X4.2, X7.1; also elsewhere on the board
LADEN_BUCHSE: D6.1 (K), K2.14 (S), U$18.P$1, U$18.P$2, U$18.P$3, U$18.P$4, U$21.P$1, U$21.P$2, U$21.P$3, U$21.P$4; also elsewhere on the board
MOSFET_PC_REMOTE: Q10.1 (G), R28.1; also elsewhere on the board
unnamed: D3.2 (A), K2.A2 (2), Q8.2 (D)
PC_REMOTE_ANSCHLUSS: Q10.2 (D), U$25.P$1, U$25.P$2, U$25.P$3, U$25.P$4
PC_REMOTE_LED: R42.1, U$28.P$1, U$28.P$2, U$28.P$3, U$28.P$4
PC_REMOTE_LED_3V3: D11.1 (K), R42.2; also elsewhere on the board
RELAIS_FAN: Q8.1 (G), R27.1; also elsewhere on the board
RELAIS_R1_R2: Q11.1 (G), R29.1; also elsewhere on the board
RELAIS_R1_R2_ANSCHLUSS: D6.2 (A), Q11.2 (D), U$20.P$1, U$20.P$2, U$20.P$3, U$20.P$4
RELAIS_R3: Q12.1 (G), R30.1; also elsewhere on the board
RELAIS_R3_ANSCHLUSS: D10.2 (A), Q12.2 (D), U$22.P$1, U$22.P$2, U$22.P$3, U$22.P$4
ROT_CLK: SV3.5; also elsewhere on the board
ROT_DT: SV3.4; also elsewhere on the board
ROT_SW: SV3.3; also elsewhere on the board
SYSTEM: K2.12 (O), U$26.P$1, U$26.P$2, U$26.P$3, U$26.P$4
TASTER_1: R21.1, X2.1; also elsewhere on the board
TASTER_2: R22.1, X2.2; also elsewhere on the board
TASTER_3: R23.1, X3.1; also elsewhere on the board
TASTER_4: R24.1, X3.2; also elsewhere on the board
TASTER_5: R25.1, X4.1; also elsewhere on the board
VCC: D10.1 (K), U$23.P$1, U$23.P$2, U$23.P$3, U$23.P$4; also elsewhere on the board

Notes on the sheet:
POWER & ADC PORTS
Extensionports ADC
Switches Display
Extension Rotary-Switch
DS18B20 Port
Relaissteuerung R1&R2
Relaissteuerung R3
Relaissteuerung Fan Batterie/Ladebuchse
MOSFET Remote-Switch PC
Status-LED PC Port

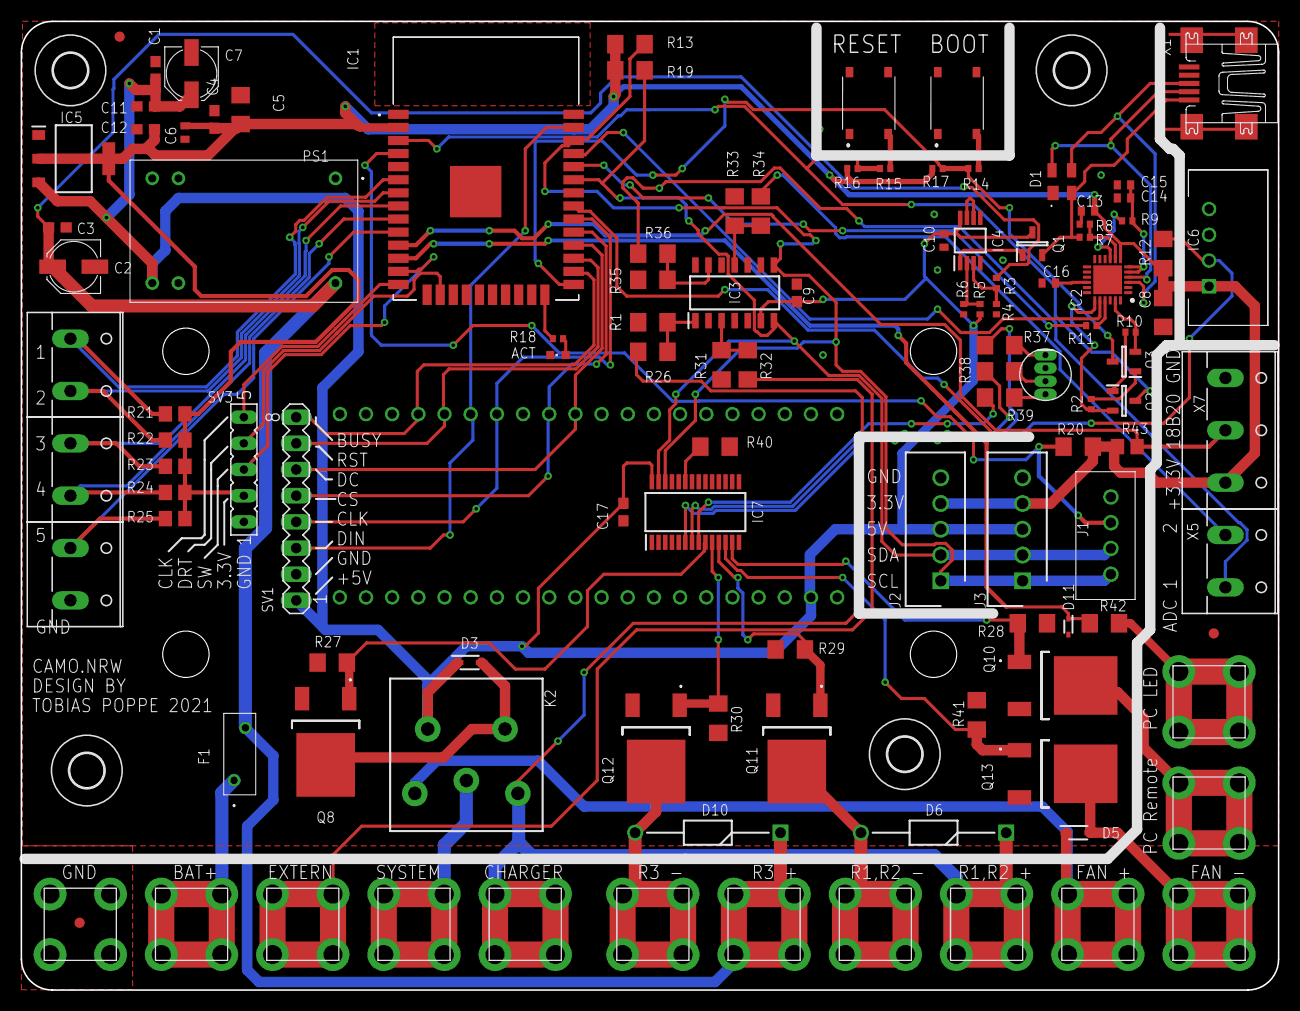
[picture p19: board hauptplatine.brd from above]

Board: 2 copper layers, 122.0 x 94.0 mm, 120 parts (1 on the bottom side), 77 nets.

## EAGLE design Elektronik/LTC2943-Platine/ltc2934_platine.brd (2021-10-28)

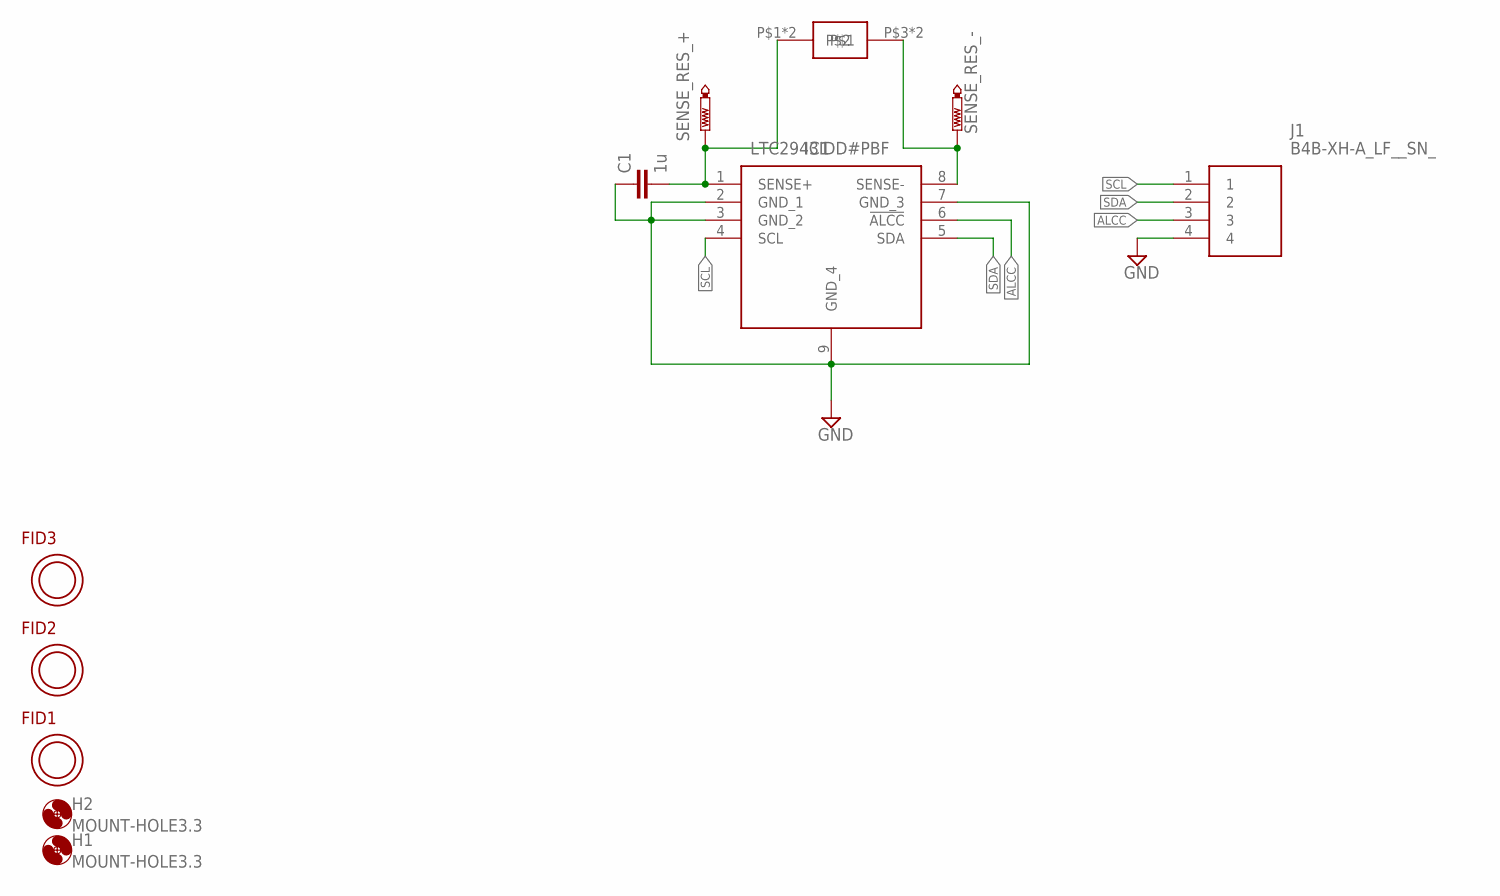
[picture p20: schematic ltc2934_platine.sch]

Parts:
C1: 1u; C1206
FID1, FID2, FID3: OPEN-PNP-FIDUCIAL
H1, H2: MOUNT-HOLE3.3; 3,3
IC1: LTC2943IDD#PBF; SON50P300X300X80-9N
J1: B4B-XH-A_LF__SN_; B4BXHALFSN
SENSE_RES_+: PTR1PAD1-13Y; P1-13Y
SENSE_RES_-: PTR1PAD1-13Y; P1-13Y
U$1: SHUNT_50A_75MV

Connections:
ALCC: IC1.6 (!ALCC), J1.3
GND: C1.1, IC1.2 (GND_1), IC1.3 (GND_2), IC1.7 (GND_3), IC1.9 (GND_4), J1.4
SCL: IC1.4 (SCL), J1.1
SDA: IC1.5 (SDA), J1.2
SENSE+: C1.2, IC1.1 (SENSE+), SENSE_RES_+.TP, U$1.P$1, U$1.P$6
SENSE_-: IC1.8 (SENSE-), SENSE_RES_-.TP, U$1.P$3, U$1.P$5

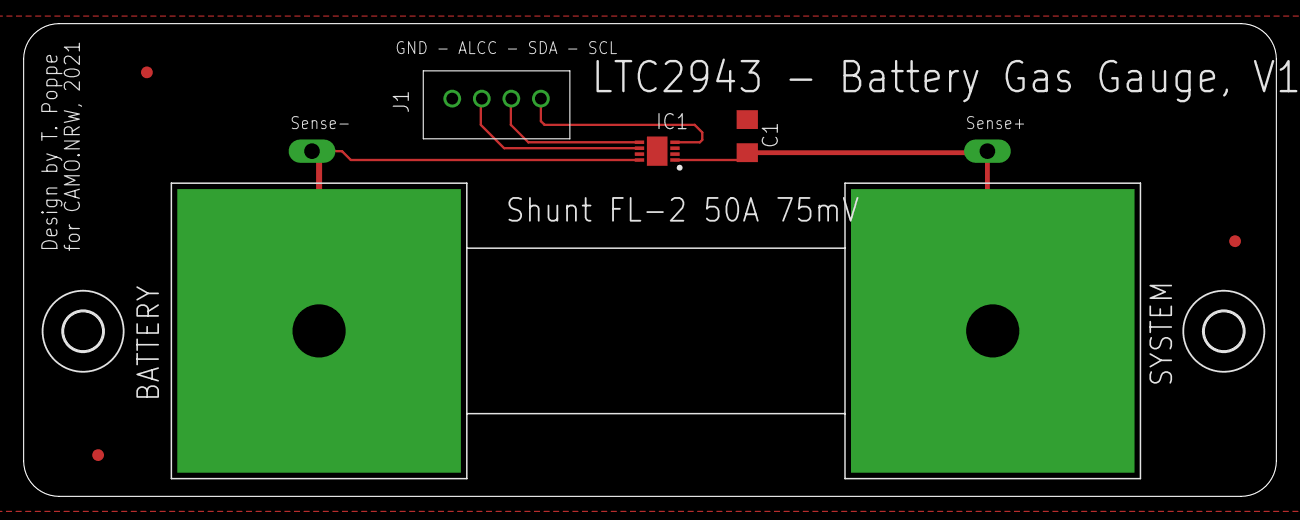
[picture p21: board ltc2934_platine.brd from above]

Board: 2 copper layers, 106.0 x 40.0 mm, 11 parts (0 on the bottom side), 6 nets.

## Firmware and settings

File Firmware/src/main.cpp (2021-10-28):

/** 
 * @file main.cpp
 * @author Tobias Poppe
 * @date 28.10.2021
 * @brief Main-File for the CAMO.NRW Firmware
 *
 * This file is the main.cpp file of the CAMO.NRWs Mainboard Firmware
 * All files and the documentation can be found on https://github.com/topoppe/camo.nrw.dachbox
 * @see https://www.camo.nrw
 * @see https://github.com/topoppe/camo.nrw.dachbox
 */

#include <Arduino.h>
#include "PCA9685.h"
#include <Adafruit_Sensor.h>
#include <DHT.h>
#include <DHT_U.h>
#include <OneWire.h>
#include <DallasTemperature.h>
#include <ros.h>
#include <std_msgs/Float32.h>

/**
 * Define Debug-State, Pins and bat-capacity
 *
 */

#define DEBUG false //true: send plain debug-messages on UART, false: send ROS-Data on UART

#define DHTTYPE DHT22
#define DHTPIN 19
#define DS18B20_PIN 26
#define LTC2943_ALCC_PIN 36
#define taster_1_PIN 34
#define taster_2_PIN 35
#define taster_3_PIN 32
#define taster_4_PIN 33
#define taster_5_PIN 25
#define pc_remote_led_PIN 27
#define on_board_led_PIN 2

#define pwm_port_rgb_led_blau 0
#define pwm_port_rgb_led_rot 1
#define pwm_port_rgb_led_gruen 2
#define pwm_port_relais_fan 3
#define pwm_port_relais_r3 4
#define pwm_port_relais_r1_r2 5
#define pwm_port_fan_pwm 6
#define pwm_port_mosfet_pc_remote 7

#define battery_capacity 27 // Define Battery-Capacity to 27Ah

struct messwerte /*! struct for all measurment-data */
{
  float dht_temperature, dht_humidity;
  float ds18b20_temperature;
  float ltc2943_spannung, ltc2943_strom, ltc2943_temperature, battery_percent;
  uint16_t ltc2943_coulomb;
  float adc_extern_1, adc_charger, adc_externe_stromversorgung, adc_extern_2;
};

// --------------- Deep-Sleep-Settings  /*! Conversion factor for micro seconds to seconds */
#define uS_TO_S_FACTOR 1000000 /*! Conversion factor for micro seconds to seconds */
#define TIME_TO_DEEPSLEEP 60   /*! Time ESP32 will go to sleep (in seconds)  */

RTC_DATA_ATTR bool system_an;          /*! bool if the system is switched on or off, stored in deepsleep-save memory */
RTC_DATA_ATTR bool first_start = true; /*! bool for init the mcp3428 only at coldstart, stored in deepsleep-save memory */
RTC_DATA_ATTR uint8_t relais_mode = 0; /*! relaismode, stored in deepsleep-save memory */
long switch_sys_off_at_time = 0;       /*! switch of timer */

/**
 * @brief Routine for flushing the i2c-interface
 *
 */
void i2c_flush()
{
  while (Wire.available())
  {
    Wire.read();
  }
}

/**
 * @brief Routines for accesing the PCA9685 pwm-controller
 *
 */
RTC_DATA_ATTR PCA9685 pwmController; /*! Library using default B000000 (A5-A0) i2c address, and default Wire @400kHz */

/**
 * @brief Initialize the pwm-controller
 *
 */
void pwm_setup()
{
  pwmController.resetDevices();        /*! Resets all PCA9685 devices on i2c line */
  pwmController.init();                /*! Initializes module using default totem-pole driver mode, and default disabled phase balancer */
  pwmController.setPWMFrequency(1000); /*! Set PWM freq to 1000Hz (default is 200Hz, supports 24Hz to 1526Hz) */
}

/**
 * @brief Switch the relais 1 & 2 between using battery for the system or charging the battery
 *
 * @param on bool input for setting the relais to system-battery-powered (true) or charge the battery (false)
 */
void relais_switch_to_charge(bool on)
{
  if (on)
    pwmController.setChannelPWM(pwm_port_relais_r1_r2, 4096);
  else
    pwmController.setChannelPWM(pwm_port_relais_r1_r2, 0);
}

/**
 * @brief Switch the relais 3 between using battery or external power-suplly for the system
 *
 * @param on bool input for setting the relais to system-battery-powered (true) or external power-supply (false)
 */
void relais_switch_system_on_bat(bool on)
{
  if (on)
    pwmController.setChannelPWM(pwm_port_relais_r3, 4096);
  else
    pwmController.setChannelPWM(pwm_port_relais_r3, 0);
}

/**
 * @brief Set the fan-speed according to the temperature
 * temperature < 40 degree Celsius: Fans off
 * temperature > 70 degree Celsius: Fans at highets speed
 * temperture between: Fan-Speed linear to temperature
 * 
 * Max Fan-Speed is limited to about 80%, due to higher system-voltage on loaeding than fans are rated!
 * @param temperatur temperature as setup for the fans
 */
void luefter_steuerung(float temperatur)
{
  if (temperatur < 40)
    pwmController.setChannelPWM(pwm_port_fan_pwm, 0);
  else if (temperatur > 70)
    pwmController.setChannelPWM(pwm_port_fan_pwm, 3275);
  else
    pwmController.setChannelPWM(pwm_port_fan_pwm, map(int(temperatur), 40, 70, 1000, 3275)); //map temperaturen between 40° and 70° to 0% and 80% fanspeed
}

/**
 * @brief Switch fan power-supply to external-connector "Load battery"
 */
void fan_relais_extern()
{
  pwmController.setChannelPWM(pwm_port_relais_fan, 4096);
}

/**
 * @brief Switch fan power-supply to internal battery
 */
void fan_relais_batterie()
{
  pwmController.setChannelPWM(pwm_port_relais_fan, 0);
}

/**
 * @brief Switch the mosfet to controll the pc´s powerswitch on or off
 *
 * @param on bool input for switch the mosfet on (true, switch pressed) or off (false, switch not pressed)
 */
void pc_remote_mosfet(bool on)
{
  if (on)
    pwmController.setChannelPWM(pwm_port_mosfet_pc_remote, 4096);
  else
    pwmController.setChannelPWM(pwm_port_mosfet_pc_remote, 0);
}

/**
 * @brief Set the color of the build-in-rgb-led
 *
 * @param rot value of the red-channel 0-255 
 * @param gruen value of the green-channel 0-255
 * @param blau value of the blue-channel 0-255
 */
void set_rgb_led(int rot, int gruen, int blau)
{
  pwmController.setChannelPWM(pwm_port_rgb_led_rot, rot << 4);     //value shifted to 12-bit value
  pwmController.setChannelPWM(pwm_port_rgb_led_gruen, gruen << 4); //value shifted to 12-bit value
  pwmController.setChannelPWM(pwm_port_rgb_led_blau, blau << 4);   //value shifted to 12-bit value
}

// ------- DHT22-Sensor Routinen -----
DHT_Unified dht(DHTPIN, DHTTYPE);

/**
 * @brief Init the DHT-Sensor
 *
 */

void dht_setup()
{
  dht.begin();
  sensor_t sensor;
  dht.temperature().getSensor(&sensor);
}

/**
 * @brief Get values from the DHT-Sensor
 * 
 * Returns the measurment value into memory. Returns NAN if sensor can´t be read
 *
 * @param dht_temperature pointer to a float variable to store the temperature value into
 * @param dht_humidity pointer to a float variable to store the humidity value into
 */
void get_dht_values(float *dht_temperature, float *dht_humidity)
{
  sensors_event_t event;
  dht.temperature().getEvent(&event);
  if (!isnan(event.temperature))
  {
    *dht_temperature = event.temperature;
  }
  else
  {
    *dht_temperature = NAN;
  }
  dht.humidity().getEvent(&event);
  if (!isnan(event.relative_humidity))
  {
    *dht_humidity = event.relative_humidity;
  }
  else
  {
    *dht_humidity = NAN;
  }
}

// ------- DS18B20-Sensor Routinen -----
OneWire ds18b20_oneWire(DS18B20_PIN);
DallasTemperature ds18b20_sensor(&ds18b20_oneWire);
DeviceAddress sensor_address;

/**
 * @brief Init the DS18B20-Sensor
 *
 */
void ds18b20_setup()
{
  ds18b20_sensor.begin();
  ds18b20_sensor.getAddress(sensor_address, 0);
  ds18b20_sensor.setResolution(sensor_address, 9);
}

/**
 * @brief Tell the DS18B20-Sensor to start a measurment. The measurments takes about 500 ms, so comeback later to read out.
 */
void ds18b20_start_meassurment()
{
  ds18b20_sensor.requestTemperatures(); // Send the command to get temperatures
}

/**
 * @brief Get values from the external DS18B20-Sensor
 * 
 * Returns the measurment value into memory. Returns NAN if sensor can´t be read
 *
 * @param dht_temperature pointer to a float variable to store the temperature value into
 */
void get_ds18b20_value(float *temperature)
{
  float tempC = ds18b20_sensor.getTempC(sensor_address);
  if (tempC != DEVICE_DISCONNECTED_C)
  {
    *temperature = tempC;
  }
  else
  {
    *temperature = NAN;
  }
}

// ------- MCP3428-ADC Routinen -----
/**
 * @brief Init the MCP3428 ADC-IC
 * 
 * In fact just a general-call reset. Resets also the PWM-IC!
 *
 */
void mcp3428_setup()
{
  Wire.beginTransmission(0x00);
  Wire.write(0x06);
  Wire.endTransmission();
  delay(1); // MC3428 benötigt 0,5ms zum reset
}

/**
 * @brief Get values from ADC-IC
 * 
 * Calculates values in Volt from the raw-adc-values and stores them into memory
 *
 * @param adc_extern_1 pointer to a float variable to store the value from adc_extern_1 in Volt into
 * @param adc_charger pointer to a float variable to store the value from the external charger-connector in Volt into
 * @param adc_externe_stromversorgung pointer to a float variable to store the value from the external power-supply-connector in Volt into
 * @param adc_extern_2 pointer to a float variable to store the value from adc_extern_2 in Volt into
 */
void get_adc_values(float *adc_extern_1, float *adc_charger, float *adc_externe_stromversorgung, float *adc_extern_2)
{
  uint8_t buffer[3] = {};
  uint8_t config = 0;
  for (uint8_t i = 0; i < 4; i++)
  {
    config = (i << 5) | 0x80;
    i2c_flush();
    Wire.beginTransmission(0x68);
    Wire.write(config);
    Wire.endTransmission();
    Wire.requestFrom(0x68, 4);
    delay(5); //wait for adc
    if (Wire.available() != 4)
      if (DEBUG)
        if (DEBUG)
          Serial.println("Read error!");

    for (uint8_t i = 0; i < 3; ++i)
      buffer[i] = Wire.read();

    long raw_result = (buffer[0] << 8) | buffer[1]; //combine 2 byte to a long value, adc returns 12-Bit-Meassurment
    if (raw_result == 0xFFFF)
      raw_result = 0;                  //Check for overflow if channel not connected
    float result = raw_result * 0.001; //Calculate Volt from Raw-Value
    result = (result * 5380) / 680;    //Calculate the Volt-Value in front of the voltagedivider
    if (i == 0)
      *adc_extern_1 = result;
    else if (i == 1)
      *adc_charger = result;
    else if (i == 2)
      *adc_externe_stromversorgung = result;
    else if (i == 3)
      *adc_extern_2 = result;
  }
}

// -------- LTC 2943 Routinen
uint8_t ltc2943_config = 0b11111000;
uint8_t ltc2943_config_standby = 0b11111001;
uint8_t ltc2943_adr = 0x64;

/**
 * @brief Init the LTC2943 battery gauge IC
 *
 */
void ltc2943_setup()
{
  Wire.beginTransmission(ltc2943_adr);
  Wire.write(0x01);
  Wire.write(ltc2943_config);
  Wire.endTransmission();
}

/**
 * @brief Switch the analog front-end of the LTC2943 into standby or vice versa. 
 * 
 * To avoid write processes while readout the LTC2943 needs to be shutdown before readout and switch again afterwards
 *
 * @param state true for switch to standby, false to switch on
 */
void ltc_2943_standby(bool state)
{
  if (!state)
  {
    Wire.beginTransmission(ltc2943_adr);
    Wire.write(0x01);
    Wire.write(ltc2943_config);
    Wire.endTransmission();
  }
  else
  {
    Wire.beginTransmission(ltc2943_adr);
    Wire.write(0x01);
    Wire.write(ltc2943_config_standby);
    Wire.endTransmission();
  }
}

/**
 * @brief tell the LTC-2943 the battery is fully charged
 */
void set_ltc_2943_coulomb_full()
{
  ltc_2943_standby(true);

  Wire.beginTransmission(ltc2943_adr);
  Wire.write(0x02);
  Wire.write(0xFF);
  Wire.write(0xFF);
  Wire.endTransmission();

  ltc_2943_standby(false);
}

/**
 * @brief Get values from LTC2943 battery gauge IC
 * 
 * Calculates values from the raw-values and stores them into memory
 *
 * @param spannung pointer to a float variable to store the voltage value at shunt into
 * @param strom pointer to a float variable to store the current value over shunt into
 * @param coulomb pointer to a float variable to store the integrated coulomb into
 * @param temperatur pointer to a float variable to store the ic´s temperature into
 * @param battery_percent pointer to a float variable to store the percentage SOC of the battery into
 */
void get_ltc2943_values(float *spannung, float *strom, uint16_t *coulomb, float *temperatur, float *battery_percent)
{
  uint8_t buffer[24] = {};
  int repeat = 0;

  ltc_2943_standby(true);
  while (repeat < 3)
  {
    i2c_flush();
    Wire.beginTransmission(ltc2943_adr);
    Wire.write(0x00);
    Wire.requestFrom(0x64, 24);
    delay(50); //wait for answer
    if (Wire.available() == 24)
    {
      for (uint8_t i = 0; i < 24; ++i)
        buffer[i] = Wire.read();
      Wire.endTransmission();
      ltc_2943_standby(false);
      break;
    }
    else
      repeat++;
  }
  if (repeat == 3)
  {
    // Read error!
    *spannung = NAN;
    *strom = NAN;
    *coulomb = NAN;
    *temperatur = NAN;
    set_rgb_led(255, 255, 255);
    Wire.endTransmission();
    ltc_2943_standby(false);
    return;
  }

  if (buffer[1] != ltc2943_config_standby)
  {
    ltc2943_setup();
  }
  else
  {
    // ----- readout voltage
    uint16_t spannung_raw = (buffer[0x08] << 8) | buffer[0x09]; //combine two int to long
    *spannung = 23.6 * (float(spannung_raw) / 65535);           //calculate voltage from raw value, see datasheet
    // ----- readout current
    uint16_t strom_raw = (buffer[0x0e] << 8) | buffer[0x0f];           //combine two int to long
    if (strom_raw < 38000)                                             //if raw value is to high, its a wrong Value, Charger is limited to 5A max;
      *strom = (0.06 / 0.0015) * ((float(strom_raw) - 32767) / 32767); //calculate current from raw value, see datasheet
    if (*strom > 0.05 && *strom <= 0.15)
      set_ltc_2943_coulomb_full(); //tell the IC battery is fully charged
    // ----- readout Coulomb-Counter
    uint16_t coulomb_counter_raw = (buffer[0x02] << 8) | buffer[0x03]; //combine two int to long
    if (coulomb_counter_raw <= 10)                                     //there is a minimal current needed by the charge-circuit. To avoid overflow of the Coulomb-Counter reset to max if overflow occured
    {
      set_ltc_2943_coulomb_full();
      coulomb_counter_raw = 0xFFFF;
    }
    *coulomb = coulomb_counter_raw;
    // ----- Temperatur auslesen
    uint16_t temperatur_raw = (buffer[0x14] << 8) | buffer[0x15];   //combine two int to long
    *temperatur = (510 * (float(temperatur_raw) / 65535)) - 273.15; //calculate temperature from raw value, see datasheet
    // --- Batterie in Prozent berechnen
    float coulomb_bat_empty = 65535 - (battery_capacity / 0.011333);              //calculate min. coulomb of the battery based on capacity
    float bat_percent_raw = map(*coulomb, 65535, int(coulomb_bat_empty), 100, 0); //map the coulomb-value to percentage
    if ((bat_percent_raw > 100) || (bat_percent_raw < 0))                         //catch if theres a failure and set percentage to zero
      bat_percent_raw = 0;
    *battery_percent = bat_percent_raw;
  }
}

// ------- E-Ink-Display Routinen -----
// Waveshare Pico-ePaper-2.9, 3-Color B/W/R, 296x128 Pixels
TaskHandle_t Task1;

#define ENABLE_GxEPD2_GFX 1
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
void loop()
{
  struct messwerte messwerte;
  struct display_data data_to_show;

  if (!system_an)
  {
    data_to_show.system_status = 0;
    if (esp_was_in_deepsleep && (esp_sleep_get_wakeup_cause() == ESP_SLEEP_WAKEUP_EXT0))
    {
      pwm_setup();
      system_an = true;
      switch_sys_off_at_time = millis() + 30000;
      if (messwerte.adc_externe_stromversorgung <= 10)
      {
        relais_switch_system_on_bat(true);
        delay(500);
      }
      pc_remote_mosfet(true);
      delay(500);
      pc_remote_mosfet(false);
    }
    else
    {
      read_all_sensors(&messwerte);
      if (DEBUG)
        Serial.print("adc extern: ");
      Serial.print(messwerte.adc_externe_stromversorgung);
      Serial.print("    adc charge: ");
      Serial.println(messwerte.adc_charger);
      if (DEBUG)
        Serial.print("Akku Coulomb: ");
      Serial.print(messwerte.ltc2943_coulomb);
      Serial.print(" = ");
      Serial.print(messwerte.battery_percent);
      Serial.println("%");
      if (DEBUG)
        Serial.print("LTC Strom: ");
      Serial.println(messwerte.ltc2943_strom);
      if (DEBUG)
        Serial.print("Relais mode: ");
      Serial.println(relais_mode);

      if ((messwerte.adc_externe_stromversorgung < 12) && (messwerte.adc_charger < 10) && (relais_mode != 1))
      { //nichts angeschlossen
        pwm_setup();
        fan_relais_batterie();
        relais_switch_to_charge(false);
        relais_switch_system_on_bat(false);
        relais_mode = 1;
      }
      if ((messwerte.adc_externe_stromversorgung >= 12) && (messwerte.adc_charger < 10) && (relais_mode != 2))
      { //Extern angeschlossen
        pwm_setup();
        fan_relais_batterie();
        relais_switch_to_charge(false);
        relais_switch_system_on_bat(false);
        relais_mode = 2;
      }
      if ((messwerte.adc_externe_stromversorgung < 12) && (messwerte.adc_charger >= 10) && (relais_mode != 3))
      { //Laden angeschlossen
        pwm_setup();
        fan_relais_extern();
        relais_switch_to_charge(true);
        relais_switch_system_on_bat(false);
        relais_mode = 3;
      }
      if ((messwerte.adc_externe_stromversorgung >= 12) && (messwerte.adc_charger >= 10) && (relais_mode != 4))
      { //Extern angeschlossen, Laden angeschlossen
        pwm_setup();
        fan_relais_extern();
        relais_switch_to_charge(true);
        relais_switch_system_on_bat(false);
        relais_mode = 4;
      }

      if (messwerte.ltc2943_strom >= 0.2)
      {
        data_to_show.ladestatus = 1;
        if (messwerte.dht_temperature > 40)
        {
          pwm_setup();
          luefter_steuerung(messwerte.dht_temperature);
        }
      }
      else
        data_to_show.ladestatus = 0;

      if (messwerte.adc_externe_stromversorgung >= 10)
      {
        data_to_show.versorgungs_art = 0;
      }
      else
      {
        data_to_show.versorgungs_art = 1;
      }

      data_to_show.akku_ladung = round(messwerte.battery_percent);
      data_to_show.temperatur = round(messwerte.dht_temperature);
      show_data_on_display(data_to_show);

      while (refresh_display_busy_flag == true)
      {
        if (!digitalRead(taster_1_PIN))
          pc_remote_mosfet(true);
        else
          pc_remote_mosfet(false);
      } //wait if display is refreshing

      ros_publish_time = 0; //Reset the last send timestamp

      esp_was_in_deepsleep = true;
      set_rgb_led(0, 0, 0);
      esp_sleep_enable_timer_wakeup(TIME_TO_DEEPSLEEP * uS_TO_S_FACTOR);
      esp_sleep_enable_ext0_wakeup(GPIO_NUM_34, LOW);
      if (DEBUG)
        Serial.println("Going to Deepsleep");
      esp_deep_sleep_start();
    }
  }

  //System an
  if (system_an)
  {
    esp_was_in_deepsleep = false;
    relais_mode = 0;
    data_to_show.system_status = 1;
    if (!digitalRead(taster_1_PIN))
      pc_remote_mosfet(true);
    else
      pc_remote_mosfet(false);

    if (digitalRead(pc_remote_led_PIN))
      set_rgb_led(255, 0, 0);
    else
      set_rgb_led(0, 0, 0);

    if (digitalRead(pc_remote_led_PIN))
      switch_sys_off_at_time = millis() + 30000;

    if (millis() > switch_sys_off_at_time)
    {
      system_an = false;
      relais_switch_system_on_bat(true);
      while (refresh_display_busy_flag == true)
      {
        if (!digitalRead(taster_1_PIN))
          pc_remote_mosfet(true);
        else
          pc_remote_mosfet(false);
      } //wait if display is refreshing
      relais_switch_to_charge(true);
      relais_switch_system_on_bat(false);
      esp_sleep_enable_timer_wakeup(TIME_TO_DEEPSLEEP * uS_TO_S_FACTOR);
      esp_sleep_enable_ext0_wakeup(GPIO_NUM_34, LOW);
      if (DEBUG)
        Serial.println("Going to Deepsleep");
      esp_deep_sleep_start();
    }

    read_all_sensors(&messwerte);
    luefter_steuerung(messwerte.dht_temperature);

    if ((messwerte.adc_externe_stromversorgung < 12) && (messwerte.adc_charger < 10))
    { //nichts angeschlossen
      fan_relais_batterie();
      relais_switch_to_charge(false);
      relais_switch_system_on_bat(true);
    }
    if ((messwerte.adc_externe_stromversorgung >= 12) && (messwerte.adc_charger < 10))
    { //Extern angeschlossen
      fan_relais_batterie();
      relais_switch_to_charge(false);
      relais_switch_system_on_bat(false);
    }
    if ((messwerte.adc_externe_stromversorgung < 12) && (messwerte.adc_charger >= 10))
    { //Laden angeschlossen
      fan_relais_extern();
      relais_switch_to_charge(false);
      relais_switch_system_on_bat(true);
    }
    if ((messwerte.adc_externe_stromversorgung >= 12) && (messwerte.adc_charger >= 10))
    { //Extern angeschlossen, Laden angeschlossen
      fan_relais_extern();
      relais_switch_to_charge(true);
      relais_switch_system_on_bat(false);
    }

    if (millis() >= ros_publish_time)
    {
      if (!DEBUG)
        ros_serial_send_msg(messwerte);
      if (DEBUG)
        Serial.print(millis());
      if (DEBUG)
        Serial.println(": Sending ROS!");
      ros_publish_time = millis() + 5000;
    }
    else if (!DEBUG)
      nh.spinOnce();

    if (messwerte.adc_externe_stromversorgung >= 10)
    {
      data_to_show.versorgungs_art = 0;
    }
    else
    {
      data_to_show.versorgungs_art = 1;
    }

    if (messwerte.ltc2943_strom >= 0.5)
    {
      data_to_show.ladestatus = 1;
    }
    else
      data_to_show.ladestatus = 0;

    data_to_show.akku_ladung = round(messwerte.battery_percent);
    data_to_show.temperatur = round(messwerte.dht_temperature);
    show_data_on_display(data_to_show);

    if (DEBUG)
    {
      Serial.println("System ist an! ");
      Serial.print("ADC Charger: ");
      Serial.println(messwerte.adc_charger);
      Serial.print("ADC Externe versorgung: ");
      Serial.println(messwerte.adc_externe_stromversorgung);
      Serial.print("LTC Spannung: ");
      Serial.println(messwerte.ltc2943_spannung);
      Serial.print("LTC Strom: ");
      Serial.println(messwerte.ltc2943_strom);
      Serial.print("LTC Coulomb: ");
      Serial.println(messwerte.ltc2943_coulomb);
      Serial.print("LTC temperatur: ");
      Serial.println(messwerte.ltc2943_temperature);
      Serial.print("LTC bat prozent: ");
      Serial.println(messwerte.battery_percent);
      delay(1000);
    }
  }
}

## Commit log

2021-10-28 Elektronik und Firmware
    [hauptplatine.brd, hauptplatine.sch, ltc2934_platine.brd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]
2021-10-29 Doku und Mechanik hochgeladen
    [Halterung Kamera BlueFOX v2.f3d, Halterung Kamera BlueFOX v2.stl, Halterung Sync-Box v2.f3d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]
